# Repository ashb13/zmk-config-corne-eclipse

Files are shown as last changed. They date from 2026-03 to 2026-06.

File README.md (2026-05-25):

README | [Keymap](KEYMAP.md) | [MX Parts](PARTS_MX.md) | [Building](BUILDING.md) | [Tricks](TRICKS.md)

# Corne Eclipse

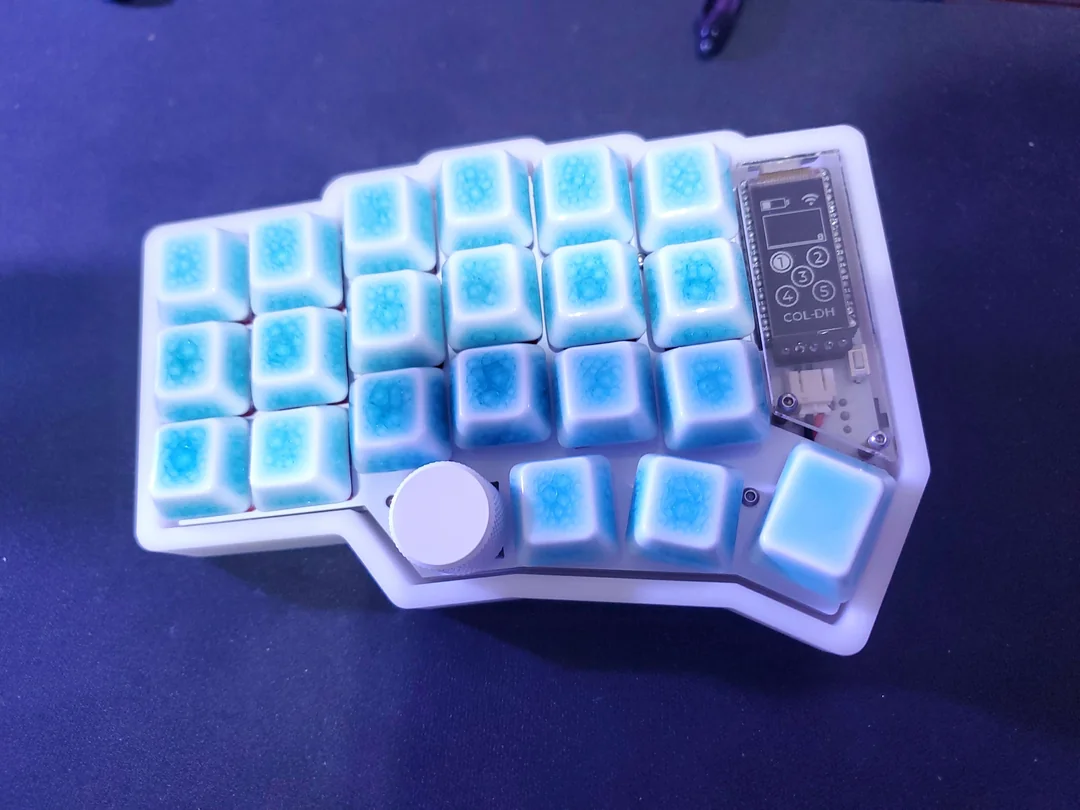
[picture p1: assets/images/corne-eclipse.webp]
Corne Eclipse With Ceramic Keys


---

Corne Eclipse Front And Back

The Corne Eclipse is a highly customized wireless Corne MX.

*This was a project I initially finished in 2021. Finally updated and open sourced!*

## Custom Circuit Board Design

- JST port with line passthrough for undercarriage battery storage
- Native support for dual nice!view displays
- Native support for dual Alps EC11/EC12 encoders
- Native support for heftier side mounted power switches
- Native support for tenting puck

## Custom Shield Casing Design

Based on Void's case.

- Undercarriage battery storage
- Optimized material usage for bottom
- Native support for tenting puck

## Peripheral-side Trackpad Support

- TPS43 (and related Azoteq IQS5xx modules) via [AYM1607/zmk-driver-azoteq-iqs5xx](https://github.com/AYM1607/zmk-driver-azoteq-iqs5xx)
- Cirque Touchpad via [petejohanson/cirque-input-module](https://github.com/petejohanson/cirque-input-module)

## ZMK Modifications

### External Display Upgrades

- Lithium curve LUT applied for a 403450 to get more accurate numeric charge data (PR reference: [ZMK PR 2066](https://github.com/zmkfirmware/zmk/pull/2066))
- Track battery status of both halves on a single nice!view
- Capslock indicator

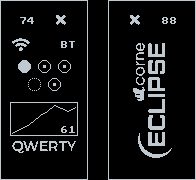
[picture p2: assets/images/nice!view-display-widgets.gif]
nice!view Display Widgets


### RGB Battery Optimizations

Powered by [zmk-ext-power-smart-idle](https://github.com/Frosthaven/zmk-ext-power-smart-idle).

- 20% brightness when not plugged in
- RGB auto-off on low battery when not plugged in
- Lights stay on when plugged in
- Eclipse v3 reversible variant uses a MOSFET that prevents drain when LEDs are off (coming soon)

## Default Typing Layouts

Available in [releases](https://github.com/ashb13/zmk-config-corne-eclipse/releases).

- QWERTY
- Colemak Mod DH (personal choice!)
- Colemak
- Workman
- DVORAK

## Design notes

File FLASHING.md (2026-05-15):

# Flashing Firmware

This guide covers how to flash firmware to the Corne Eclipse keyboard. Each half of the keyboard must be flashed separately.

## Entering Bootloader Mode

There are two ways to put a keyboard half into bootloader mode:

### Option 1: From the System Layer

1. Activate the **SYSTEM** layer (hold both lower and raise keys simultaneously)
2. Press the **Bootloader** key on the side you want to flash
   - The left **Bootloader** key puts the **left half** into bootloader mode
   - The right **Bootloader** key puts the **right half** into bootloader mode

### Option 2: Using the Physical Reset Switch

If the keyboard is unresponsive or you can't access the system layer:

1. Locate the **reset switch** on top of the board, above the power switch
2. Press the reset switch **twice in quick succession** (double-tap)
3. The keyboard half will enter bootloader mode

## Choosing the Right Firmware

Each release ships **one zip per typing layout**. Inside that zip you'll find a default and trackpad variant for each half plus a settings-reset image. You pick which `.uf2` to flash to each half based on what you've installed on that side.

`<layout>` is one of `qwerty`, `colemak_dh`, `colemak`, `workman`, `dvorak`.

```
corne_eclipse_<layout>.zip
├── left_corne_eclipse_<layout>.zmk.uf2            ← default left half
├── left_trackpad_corne_eclipse_<layout>.zmk.uf2   ← left half with trackpad instead of display
├── right_corne_eclipse_<layout>.zmk.uf2           ← default right half
├── right_trackpad_corne_eclipse_<layout>.zmk.uf2  ← right half with trackpad instead of display
└── settings_reset-nice_nano_v2-zmk.uf2            ← clean-slate / factory reset
```

**Which file do I flash to each half?**

The PCB is reversible, so you can install a trackpad on either half (or both halves, if you want two trackpads). Pick the variant per half independently:

| File | Flash to | Use when |
|---|---|---|
| `left_corne_eclipse_<layout>.zmk.uf2` | Left half | Default. Use this unless you've installed a trackpad on the left half. nice!view display is supported but optional; this firmware works with or without it. |
| `left_trackpad_corne_eclipse_<layout>.zmk.uf2` | Left half | Only if you've installed a trackpad (Azoteq IQS5xx **or** Cirque Pinnacle) on the left half. The display is disabled since the trackpad uses the display's pins. |
| `right_corne_eclipse_<layout>.zmk.uf2` | Right half | Default. Use this unless you've installed a trackpad on the right half. nice!view display is supported but optional; this firmware works with or without it. |
| `right_trackpad_corne_eclipse_<layout>.zmk.uf2` | Right half | Only if you've installed a trackpad (Azoteq IQS5xx **or** Cirque Pinnacle) on the right half. The display is disabled since the trackpad uses the display's pins. The encoder/switch still works. |

The trackpad variants bundle both Azoteq and Cirque drivers, so a single firmware works for either trackpad type. See [WIRING_TRACKPAD.md](WIRING_TRACKPAD.md) for trackpad wiring.

## Flashing the Firmware

Once a keyboard half is in bootloader mode, it will appear as a USB drive on your computer (named **NICENANO**).

1. Download `corne_eclipse_<layout>.zip` from the [releases](https://github.com/Frosthaven/zmk-config-corne-eclipse/releases) page for your desired typing layout
2. Extract the zip
3. **(Recommended)** Flash `settings_reset-nice_nano_v2-zmk.uf2` to **both halves** first to wipe any saved RGB / BLE / layer state from previous firmware. Otherwise stale NVS can override the new firmware's defaults (e.g. show wrong RGB color, stuck brightness).
4. Put the **left half** into bootloader mode
5. Drag and drop the left-half `.uf2` of your choice (default or `left_trackpad_`) onto the **NICENANO** drive
6. The drive will disconnect automatically when flashing is complete
7. Put the **right half** into bootloader mode
8. Drag and drop the right-half `.uf2` of your choice (default or `right_trackpad_`) onto the **NICENANO** drive
9. The drive will disconnect automatically when flashing is complete

Both halves should now be running the new firmware.

> ⚠️ **The keyboard half must be physically connected to your computer via USB for the `NICENANO` drive to appear.** The reset switch / bootloader key only puts the half into bootloader mode; it does not expose the drive over Bluetooth. If no drive appears after a few seconds: confirm the USB cable is a data cable (not charge-only), try a different USB port, and verify the half is actually in bootloader mode.

## RGB While Building (assembly testing)

A `_rgb_while_building_corne_eclipse.zip` bundle is also produced. Its firmware enables RGB underglow at boot so you can verify the LED chain without needing to find `RGB_TOG` in your keymap yet. Smart-idle still applies, so the LEDs follow the usual fade-off rules (30 seconds of idle on battery, 2 hours of idle on USB). QWERTY layout. Not intended for daily use.

The leading underscore in the zip name keeps this bundle at the top of the release page, separated from the daily-use layouts.

Inside the zip:

- `left_corne_eclipse_rgb_while_building.zmk.uf2` for the left half
- `right_corne_eclipse_rgb_while_building.zmk.uf2` for the right half
- `settings_reset-nice_nano_v2-zmk.uf2`

Recommended assembly sequence: **settings_reset → rgb_while_building → confirm LEDs → settings_reset → daily layout build**. The settings reset before each flash ensures the firmware's defaults take effect instead of stale NVS state.

## Resetting to Factory Settings

The `settings_reset-nice_nano_v2-zmk.uf2` is bundled inside every release zip. Flash it whenever you want to wipe stored settings (RGB state, BLE pairings, layer state, etc.) or as a clean-slate step before flashing new firmware.

1. Extract the zip you downloaded
2. Flash `settings_reset-nice_nano_v2-zmk.uf2` to **both halves** using the steps above
3. After resetting both halves, flash your desired layout firmware to both halves again

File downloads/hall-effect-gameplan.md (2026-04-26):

# Hall Effect Corne Eclipse — Implementation Gameplan

## Overview

This document details the full plan to create a hall effect (HE) variant of the Corne Eclipse split keyboard, covering PCB design, component selection, firmware integration with ZMK, and known risks.

---

## 1. Architecture Comparison

| Feature | Current Corne Eclipse | Hall Effect Variant |
|---|---|---|
| Switch type | Mechanical (Choc v1/v2, Cherry MX) | Hall effect magnetic (e.g. Gateron KS-20) |
| Sensing method | Digital matrix scan (row × col) | Analog voltage per switch via hall sensor |
| Switch pins | 2 signal pins (matrix intersection) | 3 pins (VCC, GND, analog signal) |
| Scan hardware | Direct GPIO matrix | Analog multiplexers → ADC |
| MCU | Nice!Nano (nRF52840) | Same — nRF52840 has 8 ADC channels |
| Firmware | ZMK (standard kscan driver) | ZMK + community HE module |
| Features unlocked | N/A | Adjustable actuation, rapid trigger, SOCD |

---

## 2. Component Selection

### 2.1 Hall Effect Switches

**Primary candidate: Gateron KS-20 series**
- MX-compatible housing (fits standard MX plate cutouts — 14×14mm)
- 3-pin: VCC, GND, analog signal output
- Adjustable actuation range: 0.4mm–3.6mm
- Total travel: 4.1±0.2mm
- Built-in hall effect sensor (no external sensor IC needed)
- Available in multiple spring weights (Orange 38gf, White 30gf)

**Alternative: 3D-printed Void Switches** (community, uses discrete hall sensor IC like A1304)

**Note:** Hall effect switches are NOT pin-compatible with Cherry MX mechanical switches. The center pin and signal pin positions differ. A new footprint is required.

### 2.2 Analog Multiplexers

**CD4067B (16:1 analog mux)** — industry standard
- 16 analog channels switched to 1 common output
- 4 digital select lines (S0–S3) + 1 enable
- Package: SOIC-24 or TSSOP-24
- Supply: 3.0–18V (works at 3.3V from Nice!Nano)
- On-resistance: ~125Ω at 3.3V (acceptable for analog sensing)
- Propagation delay: ~250ns

**Per-half requirements (21 switches + 1 encoder = 22 analog channels):**
- 2× CD4067B per half (16 + 6 channels used, 10 spare)
- Shared select lines: 4 GPIO pins for S0–S3
- 2 ADC pins (one per mux output)
- 2 GPIO for enable pins (optional, for power saving)

### 2.3 MCU: Nice!Nano v2 (nRF52840)

**Available ADC pins (AIN0–AIN7 on nRF52840):**

| ADC Channel | Pin | Nice!Nano Usage | Available? |
|---|---|---|---|
| AIN0 | P0.02 | GPIO | Yes |
| AIN1 | P0.03 | GPIO | Yes |
| AIN2 | P0.04 | Battery voltage | **No — reserved** |
| AIN3 | P0.05 | GPIO | Yes |
| AIN4 | P0.28 | GPIO | Yes |
| AIN5 | P0.29 | GPIO | Yes |
| AIN6 | P0.30 | GPIO | Yes |
| AIN7 | P0.31 | GPIO | Yes |

**Available: 7 ADC channels** (AIN2 reserved for battery). Only 2 needed for the mux outputs. Remaining 5 are available for other analog functions if needed.

**GPIO needed per half:**
- 4× mux select lines (S0–S3, shared between both muxes)
- 2× mux enable (optional)
- 2× ADC input (one per mux)
- Total: 6–8 GPIO/ADC pins for the switch matrix

This leaves enough remaining pins for: RGB LED data, I2C (OLED/nice!view), encoder, reset, battery.

### 2.4 Passive Components

- 2× 0.1µF bypass capacitors per CD4067B (VDD-VSS decoupling)
- 1× 10µF bulk capacitor per half (power rail stabilization)
- Optional: RC low-pass filter per mux output (e.g. 100Ω + 10nF) to reduce ADC noise

---

## 3. PCB Design

### 3.1 What Carries Over From Current Design

- Board outline / Edge.Cuts (identical form factor)
- Mounting holes and tenting puck positions
- Nice!Nano MCU footprint and placement
- Nice!View connector position
- JST battery connector
- TRRS/serial connection (for wired split, if used)
- Case, plate, and cover geometry
- GLOW underglow LED positions and wiring (WS2812B chain is independent of switch sensing)
- RGBMOS power switching circuit

### 3.2 What Must Change

**Switch footprint — NEW required:**
- Hall effect switches (Gateron KS-20) have 3 pins in different positions than MX
- Need: VCC, GND, and signal traces per switch
- Center post hole likely similar to MX (4mm) but verify against KS-20 datasheet
- Plate cutout: 14×14mm (same as MX, so existing MX plates may work)
- No hotswap socket — KS-20 switches are PCB-mount (solder-in) unless a HE-specific hotswap socket exists

**No row/col matrix — replaced with:**
- VCC bus: all switches share a common 3.3V power rail
- GND bus: all switches share common ground
- Individual signal traces: each switch's analog output routes to one mux input
- Mux outputs route to MCU ADC pins

**New components on PCB:**
- 2× CD4067B multiplexer ICs (SOIC-24 or TSSOP-24)
- Bypass capacitors
- Optional analog filtering

**Removed from PCB:**
- Diodes (no matrix → no diodes needed, saves 42 components per board)
- Row/column traces

### 3.3 Wiring Diagram (Per Half)

```
                        ┌─────────────┐
  Switch 1  signal ───▶ │ CH0         │
  Switch 2  signal ───▶ │ CH1         │
  Switch 3  signal ───▶ │ CH2         │
  ...                   │   CD4067B   │──▶ COM ──▶ MCU ADC AIN0
  Switch 16 signal ───▶ │ CH15    #1  │
                        │             │
                        │ S0 S1 S2 S3 │◀── MCU GPIO (shared)
                        │ EN          │◀── MCU GPIO (optional)
                        └─────────────┘

                        ┌─────────────┐
  Switch 17 signal ───▶ │ CH0         │
  Switch 18 signal ───▶ │ CH1         │
  ...                   │   CD4067B   │──▶ COM ──▶ MCU ADC AIN1
  Switch 22 signal ───▶ │ CH5     #2  │
                        │             │
                        │ S0 S1 S2 S3 │◀── MCU GPIO (shared with #1)
                        │ EN          │◀── MCU GPIO (optional)
                        └─────────────┘

  All switches VCC ──── 3.3V rail
  All switches GND ──── GND rail
```

### 3.4 PCB Layout Guidelines

1. **Keep analog traces short** — route switch signals to the nearest mux with minimal trace length to reduce noise pickup
2. **Separate analog and digital** — don't route mux select lines parallel to analog signal traces
3. **Ground plane** — use a solid ground pour under the mux ICs and analog traces
4. **Bypass caps** — place 0.1µF caps as close as possible to each CD4067B VDD/VSS pins
5. **Mux placement** — place one mux near the main key cluster, one near the thumb cluster or split between regions to minimize trace lengths
6. **Star ground** — connect all switch GND pins and mux GND to the same ground pour, avoid daisy-chaining
7. **ADC trace routing** — keep mux COM output → MCU ADC traces short and away from digital noise (RGB data line, I2C clock, etc.)
8. **Optional low-pass filter** — place RC filter pads between mux COM output and ADC input for noise reduction

### 3.5 Per-Key LED Consideration

SHINE per-key LEDs (LED_choc_6028R reverse mount) can remain, but:
- The LED light-pipe hole position must align with the KS-20's LED window (verify against KS-20 datasheet — may differ from MX)
- If KS-20 doesn't have an LED window, per-key backlighting through the switch won't work and LEDs should be repositioned or removed
- Underglow (GLOW WS2812B) is unaffected

---

## 4. Firmware: ZMK Integration

### 4.1 Community Module

**Repository:** [cr3eperall/zmk-feature-hall-effect](https://github.com/cr3eperall/zmk-feature-hall-effect)

**Features provided:**
- Adjustable actuation point (runtime configurable)
- Rapid trigger (re-actuation on direction change)
- SOCD (simultaneous opposing cardinal direction handling)
- Mouse input emulation
- Gamepad input emulation
- Split keyboard support (`he,input-split` binding)

**Drivers available:**
- `he,kscan-direct-pulsed` — for direct ADC wiring (not practical for 42 switches)
- `he,kscan-multiplexer` — for CD4067B mux wiring (this is what we need)

### 4.2 Integration Steps

1. **Add module to ZMK config:**
   ```yaml
   # In west.yml manifest
   projects:
     - name: zmk-feature-hall-effect
       url: https://github.com/cr3eperall/zmk-feature-hall-effect
       revision: main
   ```

2. **Create devicetree overlay** for the Corne Eclipse HE variant:
   - Define 2× CD4067B mux instances with select GPIO pins and ADC channel
   - Map each switch to a mux channel
   - Configure actuation thresholds, rapid trigger parameters
   - Set up `he,input-split` for the peripheral half

3. **Calibration routine:**
   - Each hall sensor has slightly different voltage range
   - Need to implement or use the module's calibration to map raw ADC values → distance
   - Store calibration data in flash/settings

4. **Battery monitoring:**
   - The module includes a custom battery driver for nRF52840
   - AIN2 (P0.04) remains dedicated to battery voltage sensing (unchanged)

### 4.3 Known Firmware Limitations

- **nRF52840 ADC anomaly (errata 212):** certain chip revisions (CKAA-Dx0 or QIAA-Dx0) have a bug where switching between single-channel and multi-channel ADC modes breaks the ADC. The module works around this by using single-mode continuously. Verify your Nice!Nano's chip revision.
- **Scan rate:** analog sensing is slower than digital matrix scan. With 2 muxes × 16 channels × ADC conversion time (~15µs per sample at 10-bit), expect ~0.5ms per full scan — still well under 1ms, adequate for 1000Hz+ polling.
- **No official ZMK merge yet:** the community module is not part of mainline ZMK. You depend on the module author for updates. However, PR #2980 on the ZMK repo suggests official support is being worked on.

---

## 5. Implementation Phases

### Phase 1: Validate Hardware (1–2 weeks)
- [ ] Obtain Gateron KS-20 switches and measure exact pin positions, center post diameter, and overall dimensions
- [ ] Create KiCad footprint for KS-20 (or find community footprint)
- [ ] Prototype one switch + CD4067B + Nice!Nano on a breadboard/perfboard
- [ ] Verify ADC readings through the mux with the cr3eperall ZMK module
- [ ] Test calibration and actuation point adjustment
- [ ] Verify Nice!Nano chip revision for ADC errata 212

### Phase 2: PCB Design (2–3 weeks)
- [ ] Copy the Corne Eclipse MX board as starting point (outline, mounting holes, MCU, connectors)
- [ ] Remove all SW/ENC footprints, diodes, and matrix traces
- [ ] Create and place KS-20 switch footprints at same grid positions
- [ ] Place 2× CD4067B mux ICs per half
- [ ] Route VCC/GND buses to all switches
- [ ] Route individual analog signal traces from switches to mux inputs
- [ ] Route mux select lines (4× GPIO) and COM outputs (2× ADC)
- [ ] Add bypass caps and optional RC filters
- [ ] Run DRC, verify clearances
- [ ] Update plate files if KS-20 cutout differs from MX

### Phase 3: Firmware (1–2 weeks, parallel with Phase 2)
- [ ] Fork ZMK config, add cr3eperall/zmk-feature-hall-effect module
- [ ] Write devicetree overlay for Corne Eclipse HE with mux driver
- [ ] Implement per-switch channel mapping
- [ ] Configure split keyboard communication with `he,input-split`
- [ ] Test rapid trigger and SOCD features
- [ ] Implement and test calibration storage

### Phase 4: Fabrication & Assembly (2–3 weeks)
- [ ] Order PCBs (JLCPCB, same process as current boards)
- [ ] Order components: KS-20 switches, CD4067B, passives
- [ ] Solder and assemble
- [ ] Flash firmware, run calibration
- [ ] Verify all 42 switches respond with correct analog range
- [ ] Test split communication, battery life, RGB

### Phase 5: Refinement
- [ ] Tune actuation points and rapid trigger sensitivity
- [ ] Profile battery life impact (analog sensing draws more power than digital matrix)
- [ ] Consider power optimization: disable mux enable pins when idle, reduce scan rate during idle
- [ ] Evaluate whether per-key LEDs align with KS-20 LED window

---

## 6. Bill of Materials (Per Half)

| Component | Quantity | Package | Notes |
|---|---|---|---|
| Gateron KS-20 switch | 21 (+1 encoder?) | Through-hole | Verify encoder compatibility |
| CD4067B mux | 2 | SOIC-24 or TSSOP-24 | 16-ch analog mux |
| 0.1µF ceramic cap | 4 | 0402 or 0603 | Mux bypass (2 per mux: VDD-VSS, VEE-VSS) |
| 10µF ceramic cap | 1 | 0603 or 0805 | Bulk power rail decoupling |
| 100Ω resistor (optional) | 2 | 0402 or 0603 | RC filter per mux output |
| 10nF ceramic cap (optional) | 2 | 0402 or 0603 | RC filter per mux output |
| Nice!Nano v2 | 1 | Module | nRF52840-based |
| Nice!View | 1 | Module | OLED display |
| WS2812B (GLOW) | 6 | PLCC4 5×5mm | Underglow LEDs (unchanged) |
| LED_6028R (SHINE) | 21 | 6028 reverse mount | Per-key LED (if KS-20 has LED window) |
| AO3401A MOSFET | 1 | SOT-23-3 | RGB power switch (unchanged) |
| Resistors (RGB) | 1 | 0402/0603 | Gate pullup for MOSFET (unchanged) |
| JST connector | 1 | PH 2-pin | Battery (unchanged) |
| Tenting puck mount | 1 | Custom | 3× M2 holes (unchanged) |

---

## 7. Open Questions & Risks

1. **KS-20 exact footprint** — no public KiCad footprint exists. Need to measure switches or find community footprint. Pin positions, center post size, and alignment pin locations are unknown until hands-on measurement.

2. **Hotswap for HE switches?** — standard Kailh hotswap sockets won't work (different pin layout). Mill-Max sockets on individual pins might work but adds height and cost. Likely solder-only initially.

3. **Encoder compatibility** — the rotary encoder (EC11/EC12) is a mechanical device, not hall effect. It can remain as-is with its own GPIO pins. However, if a switch shares the encoder position (ENC_SW combo footprint), that switch portion needs to be hall effect while the encoder remains digital. This requires careful pin routing — the encoder's digital output goes to GPIO, the switch's analog output goes to mux.

4. **Battery life** — analog sensing draws more current than passive digital matrix scan. The CD4067B draws ~100µA quiescent, and each ADC conversion consumes MCU power. Estimate 10–20% reduction in battery life vs current design. Can be mitigated by reducing scan rate during idle and disabling mux enable pins during sleep.

5. **Nice!Nano chip errata** — verify your specific Nice!Nano's nRF52840 chip revision isn't affected by ADC errata 212. If affected, you're limited to single-channel ADC mode (still workable with the mux approach since you read one channel at a time).

6. **Module stability** — the cr3eperall ZMK module is community-maintained, not official. If the author abandons it and ZMK's mainline PR (#2980) isn't merged, you'd need to maintain it yourself.

7. **Plate compatibility** — Gateron KS-20 uses an MX-compatible housing, so the 14×14mm plate cutout SHOULD work. Verify that the KS-20's bottom protrusions clear your current plate thickness (1.5mm for MX plates).

---

## 8. Reference Links

- [cr3eperall/zmk-feature-hall-effect](https://github.com/cr3eperall/zmk-feature-hall-effect) — ZMK community module for HE support
- [ZMK Issue #2096 — Hall Effect Support Discussion](https://github.com/zmkfirmware/zmk/issues/2096) — official issue tracker
- [ZMK PR #2980 — Hall Keyscan Driver](https://github.com/zmkfirmware/zmk/pull/2980) — WIP official driver
- [Macrolev — Open Source HE Keyboard](https://github.com/heiso/macrolev) — reference split HE keyboard design
- [Void Switch 65% — Reference HE PCB](https://github.com/riskable/void_switch_65_pct) — KiCad reference project
- [Gateron KS-20 Product Page](https://www.gateron.com/products/gateron-ks-20-magnetic-orange-hall-sensor-switch-set) — switch specs
- [CD4067B Datasheet & Design Guide](https://components101.com/article/cd4067-16-channel-analog-multiplexer-demultiplexer) — mux reference
- [nRF52840 ADC Pin Mappings](https://tomasmcguinness.com/2025/01/12/nrf52840-adc-pin-mappings/) — ADC channel reference
- [Nice!Nano Pinout](https://nicekeyboards.com/docs/nice-nano/pinout-schematic/) — MCU pin availability
- [Hall Effect Keyboard Sensing Explained — Deskthority](https://deskthority.net/viewtopic.php?t=18163) — theory and wiring

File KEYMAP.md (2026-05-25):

[README](README.md) | Keymap | [MX Parts](PARTS_MX.md) | [Building](BUILDING.md) | [Tricks](TRICKS.md)

## Keymap

Inspired by Cyberpunk's story of Johnny Silverhand, the Corne Eclipse comes with
the SAMURAI layout. I've used this layout since 2020 to slay everything from
video game corporations in a dystopian city to software development on the job.

The strategy I used when developing this layout is much like the strategy used
by vim/neovim: keep keys grouped by concept as much as possible. You can see
this in part by how movement is managed:

- The same key locations for movement in video games are reused for the arrow
  keys and again for mouse direction.
- The numpad is laid out like a full keyboard's numpad.

With this strategy, it makes leveraging all of the keys a lot more intuitive
than it seems at first glance.

## ZMK Studio

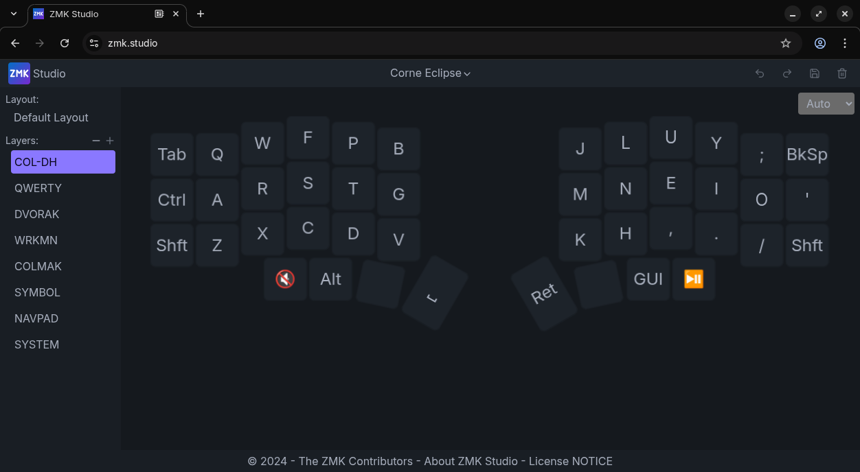
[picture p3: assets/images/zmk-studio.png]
ZMK Studio


This firmware supports [ZMK Studio](https://zmk.studio/) for changing *most* key
bindings without reflashing. You can read more about its features and
limitations on the [official documentation page](https://zmk.dev/docs/features/studio).

### Usage

1. Connect the left half via USB
2. Make sure the keyboard is in USB mode (use the `BT or USB` key on the `SYSTEM` layer to toggle)
3. Open ZMK Studio and connect
4. When prompted to unlock, press the `ZMK AUTH` key on the `SYSTEM` layer

On Linux, you may need serial port access (log out and back in after):

```bash
sudo usermod -aG uucp $USER
```

### Reset To Firmware Default Keymap

To revert to the firmware's default keymap, use the "Restore Stock Settings"
option in ZMK Studio.

## Keyboard Layers

### Typing Layers

Beyond your default typing layout, you can activate layouts 2, 3, 4, and 5 on
the `SYSTEM` layer. By default all layouts are filled with alternative keymaps:

- QWERTY
- Colemak-DH
- Colemak
- Dvorak
- Workman

The default typing layout is decided by which firmware package you install from
the [releases](https://github.com/Frosthaven/zmk-config-corne-eclipse/releases)
page. You can always return to your default layout by pressing the `LAYOUT 1`
key on the `SYSTEM LAYER`.

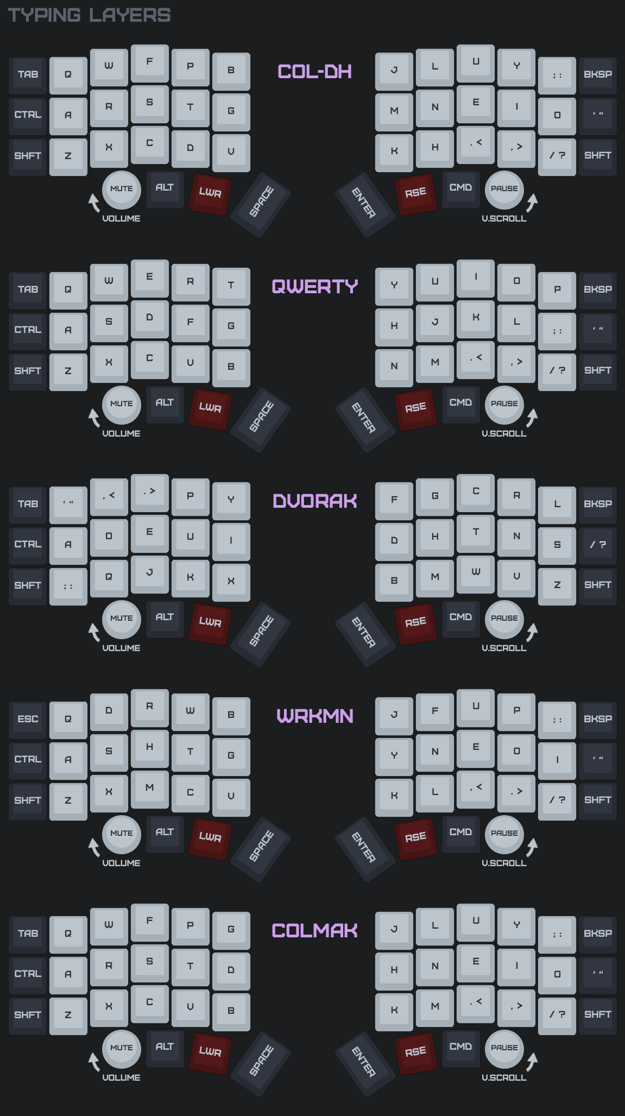
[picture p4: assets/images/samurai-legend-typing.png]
Typing Layer


### Utility Layers

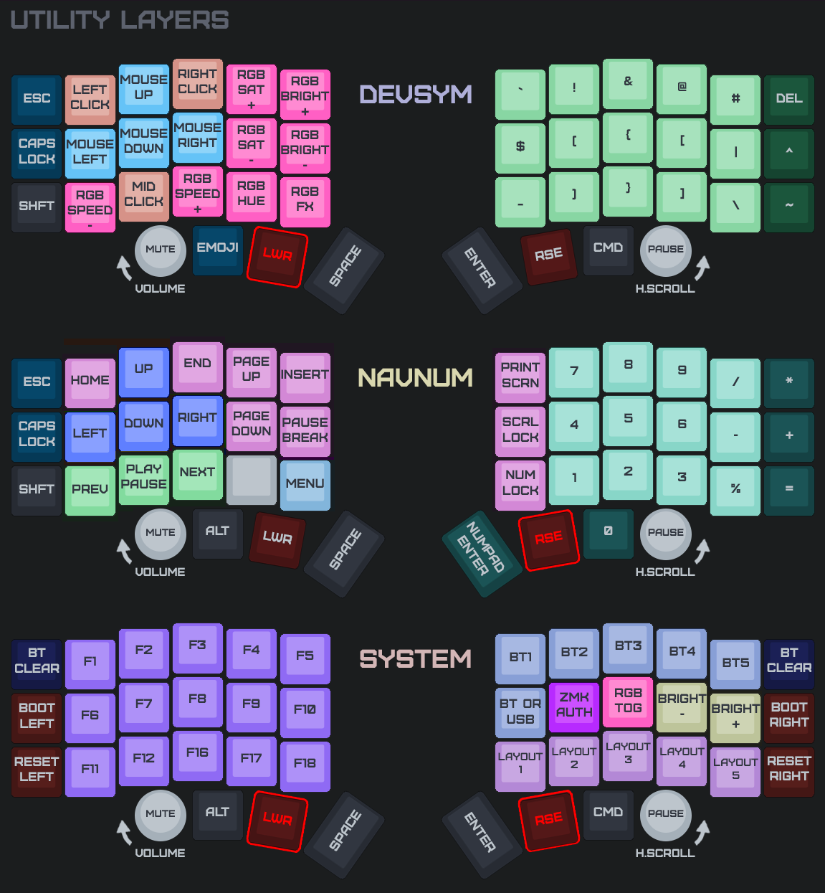
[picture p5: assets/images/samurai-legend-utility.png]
Utility Layer


## MacOS Specific Notes

<details>
<summary>Omni-shortcuts for Navigation and Text Editing</summary>

Ideally, you'd want to get used to the different keybinds on different operating
systems to save yourself a headache later. However, you can use
Karabiner-Elements to bridge the divide between Linux/Windows and Mac for most
things.

Install [Karabiner-Elements](https://karabiner-elements.pqrs.org/) via Homebrew:

```bash
brew install --cask karabiner-elements
```

Then paste the following URL into your browser address bar to import the
Omni-shortcuts:

```
karabiner://karabiner/assets/complex_modifications/import?url=https://raw.githubusercontent.com/ashb13/zmk-config-corne-eclipse/main/assets/references/karabiner-windows-shortcuts.json
```

*Note: Make sure that Corne Eclipse has both `Modify events` and `Ignore vendor
events` toggled on in Karabiner-Elements' Devices tab.*

Three rule groups — **Text Navigation**, **Text Editing**, and **App Shortcuts** — remap common shortcuts so Linux/Windows muscle memory carries over on macOS. All rules exclude terminal apps to preserve signals like `Ctrl+C`. Note: `Ctrl+Left/Right` overrides macOS Space switching (previous/next desktop).

| Key | Action |
|-----|---|
| `Home` | Beginning of line |
| `End` | End of line |
| `Shift+Home` / `Shift+End` | Select to line start/end |
| `Ctrl+Home` / `Ctrl+End` | Beginning/end of document |
| `Shift+Ctrl+Home` / `Shift+Ctrl+End` | Select to document start/end |
| `Ctrl+Left` / `Ctrl+Right` | Jump word left / right |
| `Ctrl+Shift+Left` / `Ctrl+Shift+Right` | Select word left / right |
| `Ctrl+Backspace` | Delete word backward |
| `Ctrl+Delete` | Delete word forward |
| `Ctrl+C` / `X` / `V` | Copy / Cut / Paste |
| `Ctrl+Z` / `Ctrl+Y` / `Ctrl+Shift+Z` | Undo / Redo |
| `Ctrl+A` | Select All |
| `Ctrl+S` / `Ctrl+Shift+S` | Save / Save As |
| `Ctrl+F` | Find |
| `Ctrl+R` | Reload |
| `Ctrl+W` | Close tab |
| `Ctrl+T` | New tab |
| `Ctrl+N` / `Ctrl+Shift+N` | New window / Private window |
| `Ctrl+O` | Open file |
| `Ctrl+L` | Focus address bar |
| `Ctrl+P` / `Ctrl+Shift+P` | Print / Command palette |
| `Ctrl+K` | In-app search |
| `Ctrl+D` | Bookmark / select next occurrence |
| `Ctrl+B` | Bold / toggle sidebar |
| `Ctrl+I` | Italic |

</details>

<details>
<summary>Tap Command alone → launch Raycast</summary>

A modifier-tap rule turns the Command key into a [Raycast](https://www.raycast.com/) launcher when tapped on its own: hold Command and it behaves normally for shortcuts (e.g. `Cmd+S`), tap and release it alone and it fires `Control+Space` (Raycast's default global hotkey). Released using Karabiner's `to_if_alone` with `lazy: true`, so holding Command never registers as a key event until another key joins it — there's no menu flash or stray modifier press.

Bundled into the same `karabiner-windows-shortcuts.json` import URL as the omni-shortcuts above. The rule shows up in Karabiner as a separate enable/disable toggle, so you can leave it off if you'd rather not lose tap-Command.

| Key | Action |
|-----|---|
| Tap `Cmd` (no other key) | Launch / toggle Raycast |
| Hold `Cmd` + any key | Normal Command behavior |

*Note: requires Raycast's global hotkey to be set to `Control+Space` (the default). If you've changed it, update the `to_if_alone` binding in the rule to match.*

</details>

## Linux Specific Notes

<details>
<summary>Using the Emoji key</summary>

The emoji key on the `DEVSYM` layer is a macro that presses the keys necessary
to launch the emoji picker on Windows and on MacOS. For Linux, you may need to
assign this key to your emoji picker of choice if one is not already assigned
(I'm a big fan of `smile` under Wayland). When you press the emoji key, it will
likely be detected as `Super + period`.

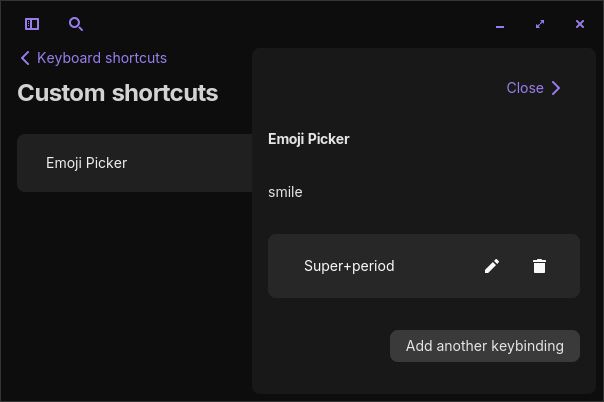
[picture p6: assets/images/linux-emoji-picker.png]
Linux Emoji Picker


</details>

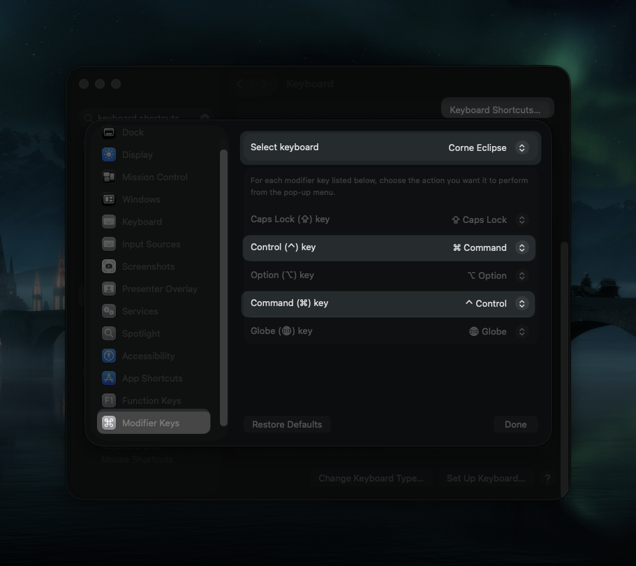
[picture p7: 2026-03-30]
assets/images/mac-rebind-modifiers.png

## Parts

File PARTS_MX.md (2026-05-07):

[README](README.md) | [Keymap](KEYMAP.md) | MX Parts | [Building](BUILDING.md) | [Tricks](TRICKS.md)

# MX Parts

## Electronics

| Required | Quantity | Part | Notes |
|---|---|---|---|
| ✅ | 2 | [nice!nano v2 Microcontroller](https://nicekeyboards.com/nice-nano/) | Bluetooth-enabled. Solder at 270-300C to avoid damaging the nRF52840 chip. |
| ✅ | 2 | [JST Connector (S2B-PH-SM4-TB)](https://www.digikey.com/en/products/detail/jst-sales-america-inc/S2B-PH-SM4-TB/926655) | For battery connection with line passthrough. |
| ✅ | 2 | [SPDT Right-Angle Slide Switch](https://www.digikey.com/en/products/detail/eao/09-10290-01/8733108) | Power switch. |
| ✅ | 2 | [750mAh Battery (403450)](https://www.amazon.com/Liter-energybattery-Battery-Rechargeable-Connector/dp/B09FSY7N9G) | 3.7V LiPo, 4 x 34 x 50mm. JST PH 2.0 terminated. Important: The hot (red) line of the battery should go on the right side when looking down at either corne pcb from above. |
| ✅ | 100+ | [SMD Diodes](https://boardsource.xyz/products/diode-smd) | 1N4148W or equivalent. |
| ✅ | 42+ | [MX Hotswap Sockets](https://cannonkeys.com/products/kailh-mx-hotswap-sockets) | For plugging your switches into. |
| ✅ | 2 | [Mill Max Low Profile Sockets & Pins](https://splitkb.com/products/mill-max-low-profile-sockets?variant=31945995845709) | For socketing the nice!nano. Make sure you get the Mil Max pins with it! |
| ✅ | 2 | [Reset Switches](https://splitkb.com/products/reset-buttons) | Tactile SMD reset switches. |
| ❌ | 1-2 | [nice!view Display](https://nicekeyboards.com/nice-view/) | The left is the most important, as it shows active bluetooth state and profile. Be sure to get pins/sockets that accomodate your socketing height of the nice!nano. |
| ❌ | 1-2 | [Alps EC11 Rotary Encoder](https://www.mouser.com/ProductDetail/Alps-Alpine/EC11N1524402?qs=W%2FMpXkg%252BdQ5mmk2EdvtXAA%3D%3D) | Alps Alpine EC11N1524402 or EC11 compatible encoder. |
| ❌ | 1 | [Azoteq TPS43 Touchpad Module](https://holykeebs.com/products/touchpad-module) | Replaces the right encoder. Requires 5 wires (SDA, SCL, RDY, VCC, GND) to the nice!nano. See [wiring guide](WIRING_TRACKPAD.md). |

## Switches & Keycaps

| Required | Quantity | Part | Notes |
|---|---|---|---|
| ✅ | 42+ | MX Switches | MX-compatible switch set. |
| ✅ | 42+ | MX Keycaps | MX-compatible keycap set. |
| ❌ | 1-2 | [Encoder Rotary Knobs](https://www.gloriousgaming.com/products/gmmk-pro-keyboard-rotary-knob) | Any EC11-compatible knobs if you installed an encoder. |

## Plates & Case

| Required | Quantity | Part | Notes |
|---|---|---|---|
| ❌ | 2 | [OLED Cover Kit](https://keebd.com/en-us/products/corne-acrylic-oled-cover-kit) | Protective acrylic covers. If you find these without the standoffs and screws, you'll need to get those yourself. |
| ❌ | 2 | [SplitKB Tenting Pucks](https://splitkb.com/products/tenting-puck?_pos=1&_sid=b9942abea&_ss=r) | Mounted to the PCB via 4 included screws. May have options that include the Manfrotto MP3-BK. |
| ❌ | 2 | [Small Desk Tripod](https://www.manfrotto.com/global-en/pocket-support-large-black-mp3-bk/) | Manfrotto MP3-BK Pocket Tripod or similar. Only if you didn't get it bundled above. |

## Hardware

I haven't yet verified the exact screws, so this list may not be exact. YMMV.

| Required | Quantity | Part | Notes |
|---|---|---|---|
| ✅ | 10 | [M2x8mm Countersunk Screws](https://www.aliexpress.us/item/2251832781782755.html) | Standoff bottom case screws. |
| ✅ | 36 | [M2x5mm Button Head Screws](https://www.aliexpress.us/item/2251832780910689.html) | Standoff top plate screws. |
| ✅ | 10 | [M2x4mm Female-Female Standoffs](https://www.amazon.com/dp/B0FLGTQZNN) |  |

## Fabrication

While the sections above cover items you can buy, this section documents
what needs to be created.

The circuit board, plates, and shields need to be fabricated by a PCB and 3D
printing company like [Elecrow](https://www.elecrow.com/),
[JLCPCB](https://jlcpcb.com/), [PCBWay](https://www.pcbway.com/), or
[OSHPark](https://oshpark.com/). I've had good work from Elecrow in the past.

### Circuit Board

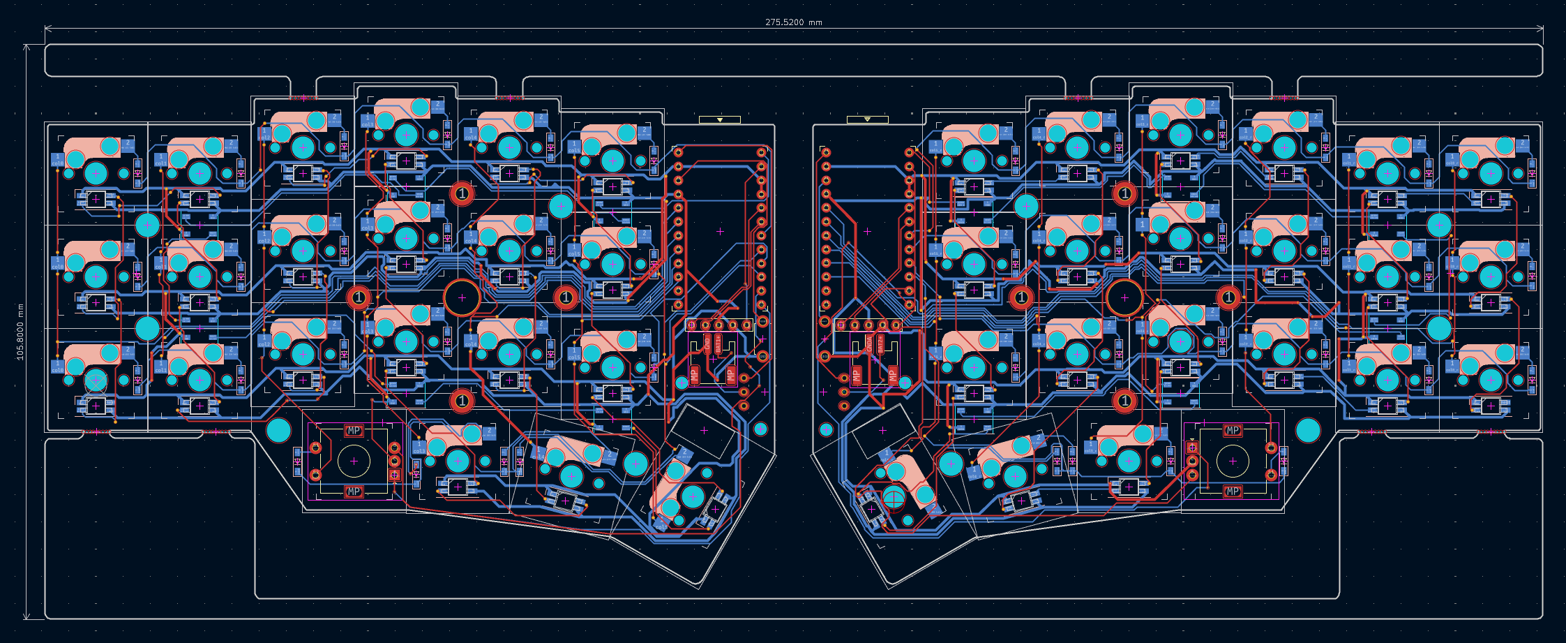
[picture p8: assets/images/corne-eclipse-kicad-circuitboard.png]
Circuit Board


Some vendors won't render the outside negative space of the circuitboard
correctly in their uploader tool, but it is still fine.

Provide these files to the fabricator:
- [corne-eclipse-mx-dual.zip](/fabrication/!for-fabricator-production/pcb/corne-eclipse-mx-dual.zip)

### Plates

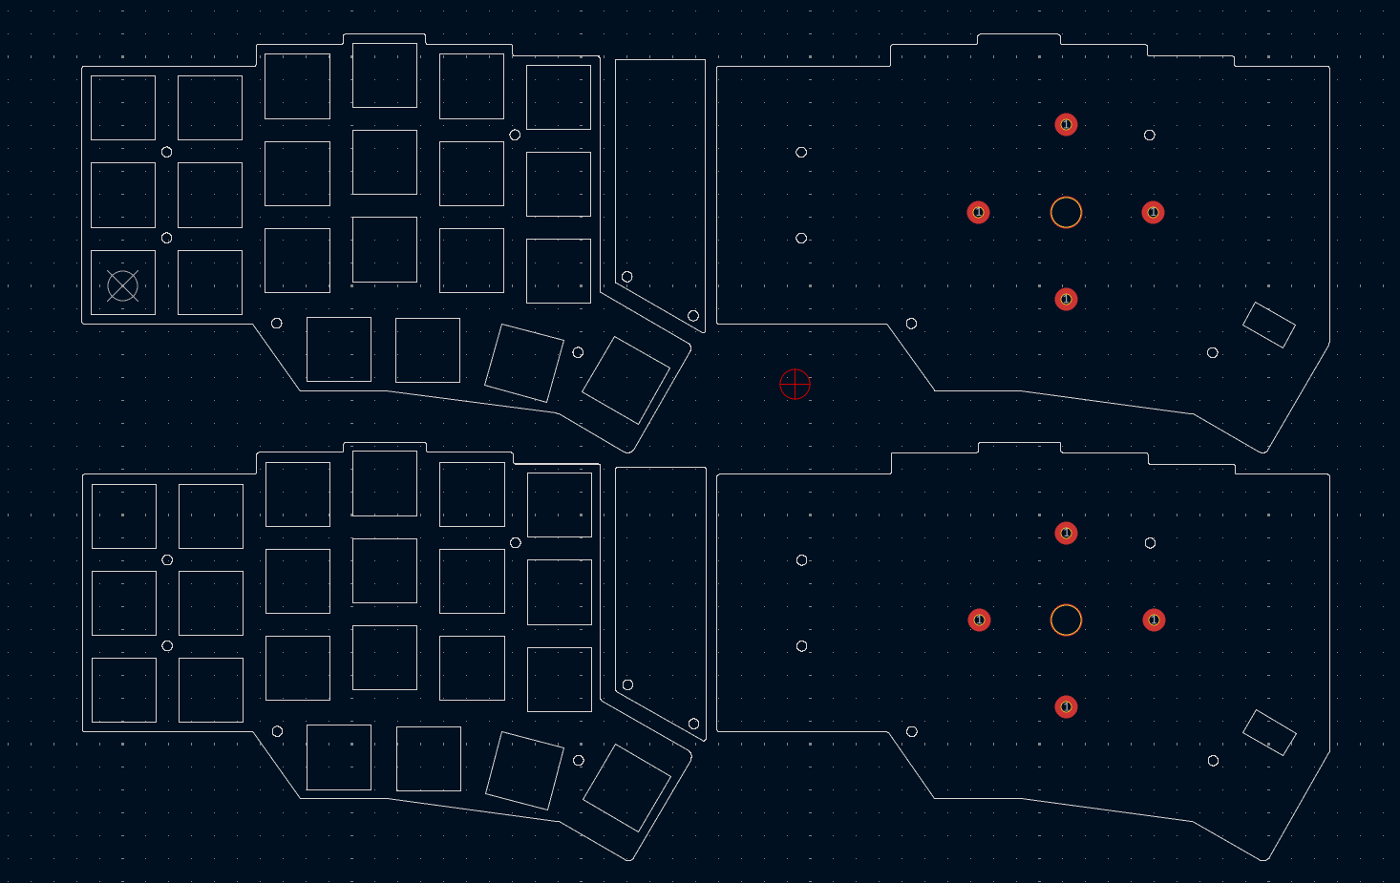
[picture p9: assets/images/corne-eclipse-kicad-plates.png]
Plates


This will need to be cut the same way that circuitboards are. There may be an
extra charge for adding break-away points to the plate print.

Provide these files to the fabricator:
- [corne-eclipse-plates-mx-or-chocv2-1.5mm.zip](/fabrication/!for-fabricator-production/pcb/corne-eclipse-plates-mx-or-chocv2-1.5mm.zip)

### Shield Case

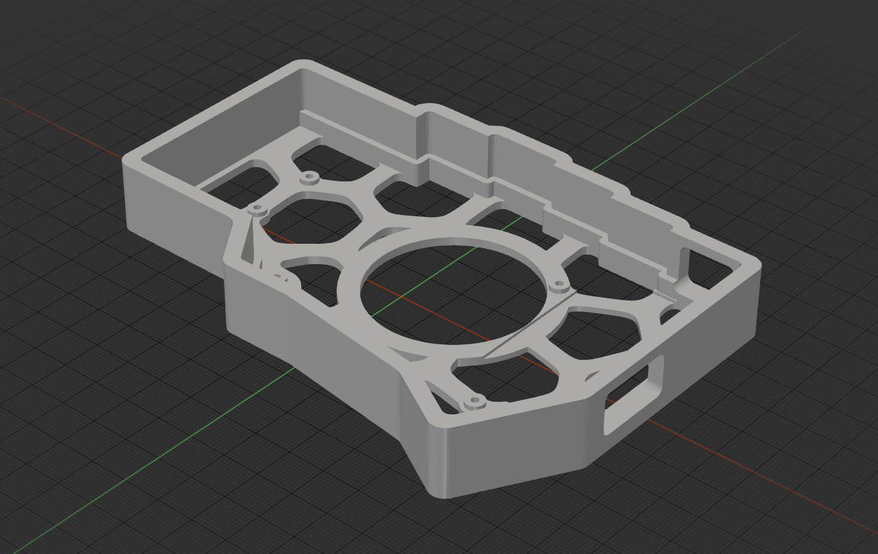
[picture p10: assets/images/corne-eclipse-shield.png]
Shield


Provide these files to the fabricator:
- [corne-eclipse-case-mx-left.stl](/fabrication/!for-fabricator-production/3dprint/cases-standard/corne-eclipse-case-mx-left.stl)
- [corne-eclipse-case-mx-right.stl](/fabrication/!for-fabricator-production/3dprint/cases-standard/corne-eclipse-case-mx-right.stl)

*Note: Some fabricators have gotten pretty good at printing this out in metal.*

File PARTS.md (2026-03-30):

[README](README.md) | [Keymap](KEYMAP.md) | Parts | [Fabrication](FABRICATION.md) | [Building](BUILDING.md) | [Tricks](TRICKS.md)

# Parts

## Electronics

| Required | Quantity | Part | Notes |
|---|---|---|---|
| ✅ | 2 | [nice!nano v2 Microcontroller](https://nicekeyboards.com/nice-nano/) | Bluetooth-enabled. Solder at 270-300C to avoid damaging the nRF52840 chip. |
| ✅ | 2 | [JST Connector (S2B-PH-SM4-TB)](https://www.digikey.com/en/products/detail/jst-sales-america-inc/S2B-PH-SM4-TB/926655) | For battery connection with line passthrough. |
| ✅ | 2 | [SPDT Right-Angle Slide Switch](https://www.digikey.com/en/products/detail/eao/09-10290-01/8733108) | Power switch. |
| ✅ | 2 | [750mAh Battery (403450)](https://www.amazon.com/Liter-energybattery-Battery-Rechargeable-Connector/dp/B09FSY7N9G) | 3.7V LiPo, 4 x 34 x 50mm. JST PH 2.0 terminated. Important: The hot (red) line of the battery should go on the right side when looking down at either corne pcb from above. |
| ✅ | 100+ | [SMD Diodes](https://boardsource.xyz/products/diode-smd) | 1N4148W or equivalent. |
| ✅ | 42+ | [MX Hotswap Sockets](https://cannonkeys.com/products/kailh-mx-hotswap-sockets) | For plugging your switches into. |
| ✅ | 2 | [Mill Max Low Profile Sockets & Pins](https://splitkb.com/products/mill-max-low-profile-sockets?variant=31945995845709) | For socketing the nice!nano. Make sure you get the Mil Max pins with it! |
| ✅ | 2 | [Reset Switches](https://splitkb.com/products/reset-buttons) | Tactile SMD reset switches. |
| ❌ | 1-2 | [nice!view Display](https://nicekeyboards.com/nice-view/) | The left is the most important, as it shows active bluetooth state and profile. Be sure to get pins/sockets that accomodate your socketing height of the nice!nano. |
| ❌ | 1-2 | [Alps EC11 Rotary Encoder](https://www.mouser.com/ProductDetail/Alps-Alpine/EC11N1524402?qs=W%2FMpXkg%252BdQ5mmk2EdvtXAA%3D%3D) | Alps Alpine EC11N1524402 or EC11 compatible encoder. |

## Switches & Keycaps

| Required | Quantity | Part | Notes |
|---|---|---|---|
| ✅ | 42+ | MX Switches | MX-compatible switch set. |
| ✅ | 42+ | MX Keycaps | MX-compatible keycap set. |
| ❌ | 1-2 | [Encoder Rotary Knobs](https://www.gloriousgaming.com/products/gmmk-pro-keyboard-rotary-knob) | Any EC11-compatible knobs if you installed an encoder. |

## Plates & Case

| Required | Quantity | Part | Notes |
|---|---|---|---|
| ❌ | 2 | [OLED Cover Kit](https://keebd.com/en-us/products/corne-acrylic-oled-cover-kit) | Protective acrylic covers. If you find these without the standoffs and screws, you'll need to get those yourself. |
| ❌ | 2 | [SplitKB Tenting Pucks](https://splitkb.com/products/tenting-puck?_pos=1&_sid=b9942abea&_ss=r) | Mounted to the PCB via 4 included screws. May have options that include the Manfrotto MP3-BK. |
| ❌ | 2 | [Small Desk Tripod](https://www.manfrotto.com/global-en/pocket-support-large-black-mp3-bk/) | Manfrotto MP3-BK Pocket Tripod or similar. Only if you didn't get it bundled above. |

## Hardware

I haven't yet verified the exact screws, so this list may not be exact. YMMV.

| Required | Quantity | Part | Notes |
|---|---|---|---|
| ✅ | 10 | [M2x8mm Countersunk Screws](https://www.aliexpress.us/item/2251832781782755.html) | Standoff bottom case screws. |
| ✅ | 36 | [M2x5mm Button Head Screws](https://www.aliexpress.us/item/2251832780910689.html) | Standoff top plate screws. |
| ✅ | 10 | [M2x8mm Female-Female Standoffs](https://www.aliexpress.us/item/2255801085594177.html) |  |

## Fabricated Parts

You will also need the following parts from the [Fabrication](FABRICATION.md) page:
- 1x Circuit board set (left and right)
- 1x Plate set (left and right)
- 1x Left Shield Case
- 1x Right Shield Case

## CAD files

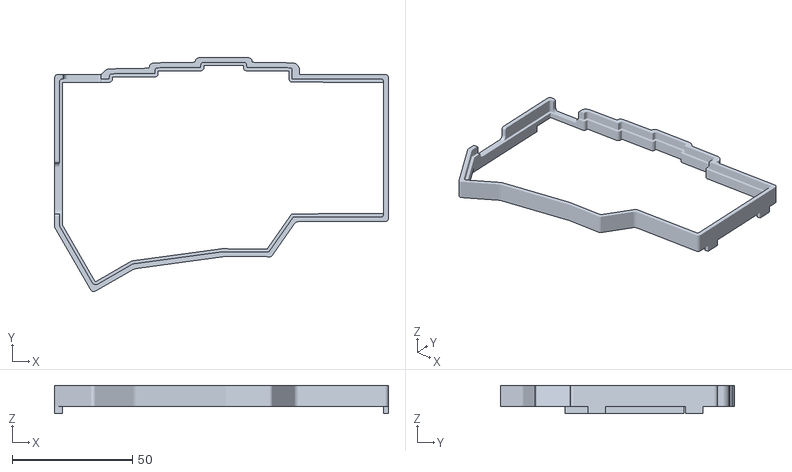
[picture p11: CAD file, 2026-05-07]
fabrication/!for-fabricator-production/3dprint/cases-rgb/corne-eclipse-acrylic-lp-open-right.stl
138.9 x 97.3 x 11.8

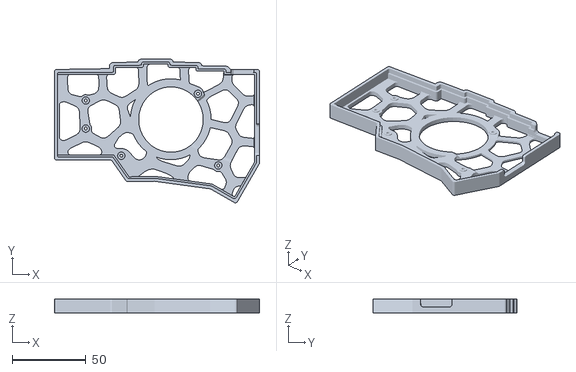
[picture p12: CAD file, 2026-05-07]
fabrication/!for-fabricator-production/3dprint/cases-standard/corne-eclipse-case-lp-left.stl
138.8 x 97.3 x 9.75

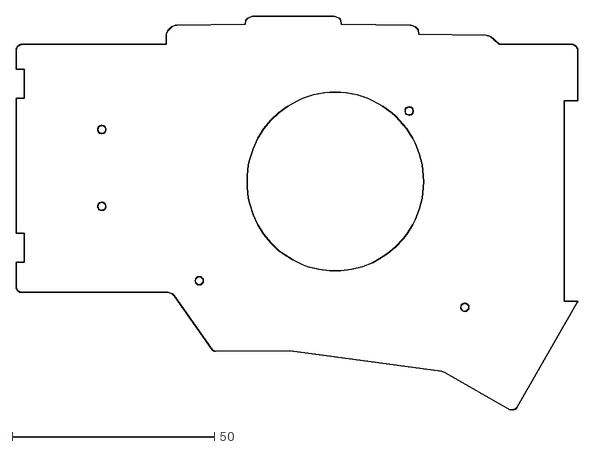
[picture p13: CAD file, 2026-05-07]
fabrication/!for-fabricator-production/cutout/corne-eclipse-shell-acrylic-base/corne-eclipse-shell-acrylic-base.dxf
138.8 x 97.3

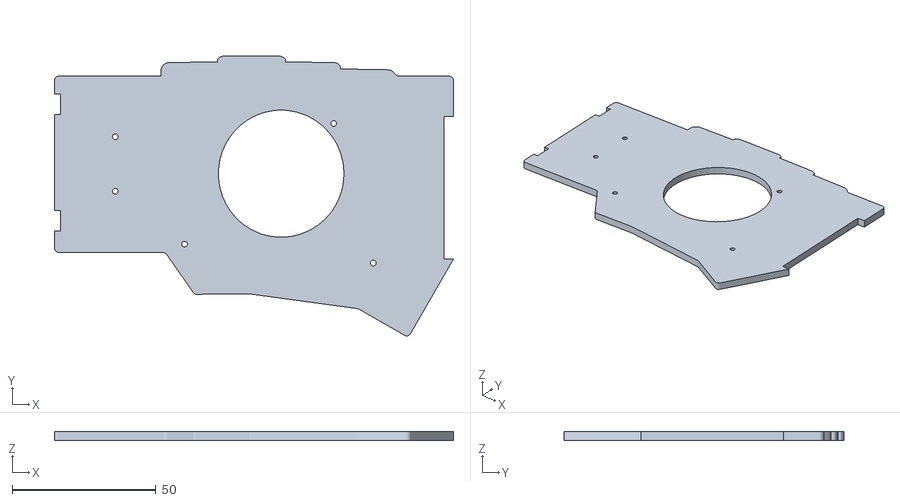
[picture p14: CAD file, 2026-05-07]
fabrication/!for-fabricator-production/cutout/sources/corne-eclipse-acrylic-lp-acrylic-only.stl
138.8 x 97.3 x 3.00

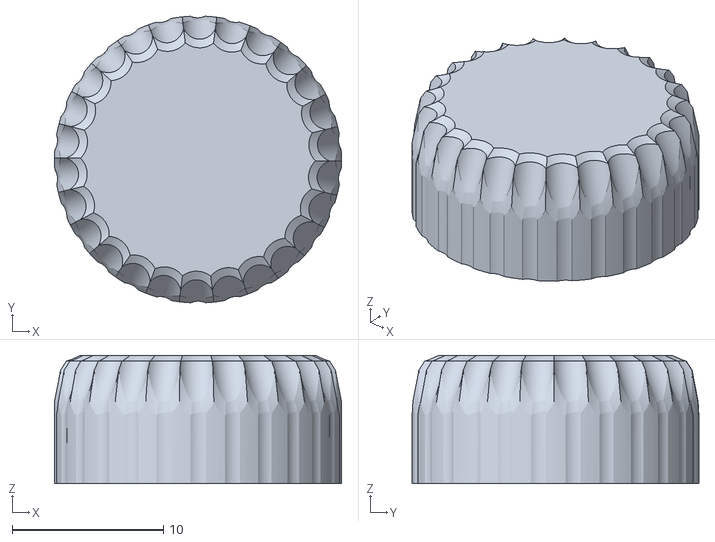
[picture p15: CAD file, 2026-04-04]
fabrication/encoder knob/ec12_with_skirt.stl
19.0 x 19.0 x 8.50

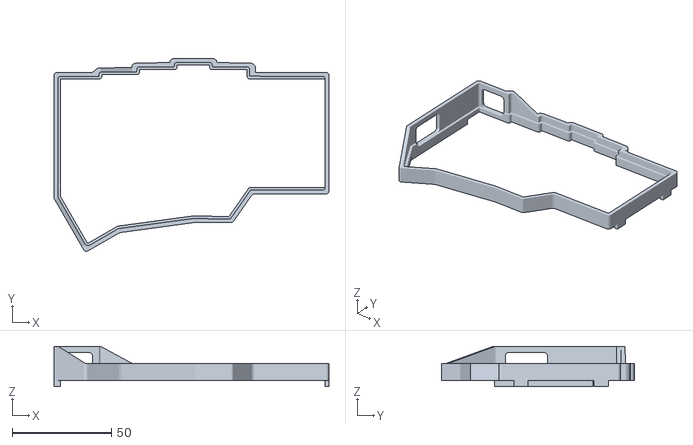
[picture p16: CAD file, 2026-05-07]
fabrication/!for-fabricator-production/3dprint/cases-rgb/corne-eclipse-acrylic-lp-closed-right.stl
138.9 x 97.3 x 20.3

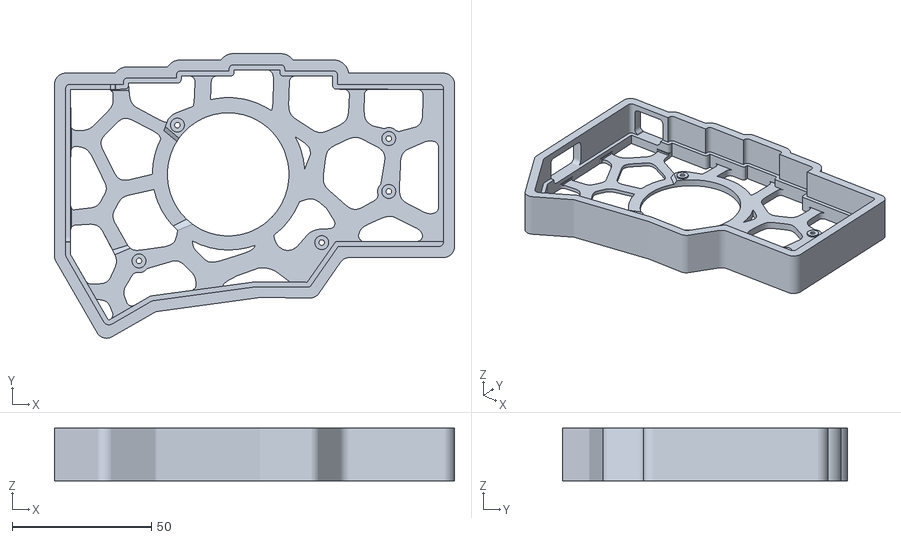
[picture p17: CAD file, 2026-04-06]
fabrication/!for-fabricator-production/3dprint/cases-standard/corne-eclipse-case-mx-right.stl
143.7 x 102.2 x 18.9

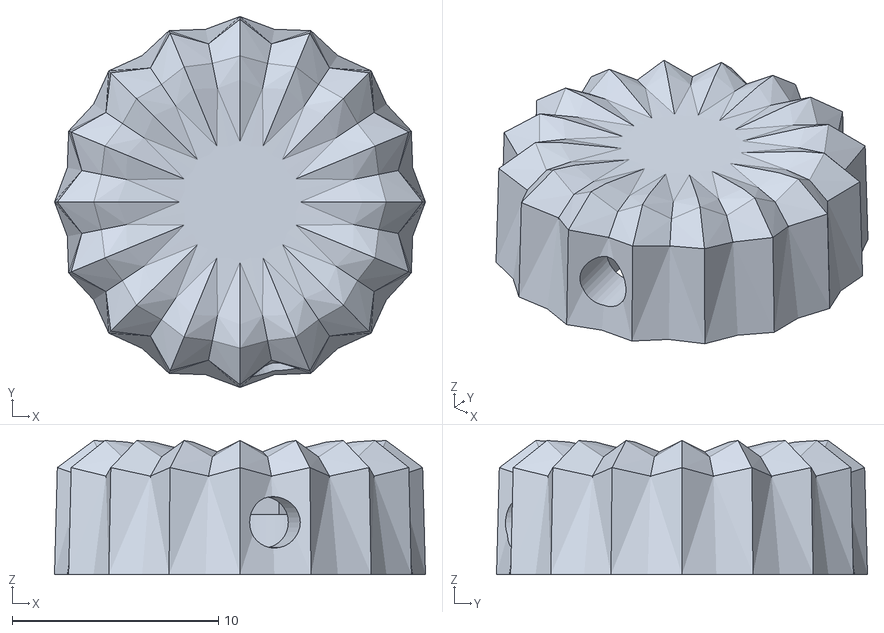
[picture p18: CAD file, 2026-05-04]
fabrication/!for-fabricator-production/3dprint/encoders/corne-eclipse-enc-lotus-lp-setscrew.stl
18.0 x 18.0 x 6.50

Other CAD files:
fabrication/!for-fabricator-production/3dprint/cases-rgb/corne-eclipse-acrylic-lp-open-left.stl
fabrication/!for-fabricator-production/3dprint/cases-standard/corne-eclipse-case-lp-right.stl
fabrication/!for-fabricator-production/3dprint/cases-rgb/corne-eclipse-acrylic-lp-closed-left.stl
fabrication/!for-fabricator-production/3dprint/cases-standard/corne-eclipse-case-mx-left.stl
assets/projects/corne-eclipse-case-lp-left.blend
assets/projects/corne-eclipse-case-mx-left.blend
assets/projects/corne-eclipse-enc-lotus.blend
assets/projects/wip/corne-eclipse-acrylic-lp-left.blend

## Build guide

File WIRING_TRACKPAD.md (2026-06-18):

[README](README.md) | [Keymap](KEYMAP.md) | [MX Parts](PARTS_MX.md) | [Building](BUILDING.md) | [Tricks](TRICKS.md)

# Wiring a Trackpad

The Corne Eclipse can host a trackpad on either half (the PCB is reversible). The same wiring approach applies to either side; just hand-wire to the pads on the half where the trackpad is installed.

Two trackpad modules are supported:

- **Azoteq TPS43** (rectangular, 43x40 mm). EOL as of April 2024; aftermarket stock only.
- **Cirque Pinnacle** (GlidePoint Circle TM040040 40 mm round / TM035035 35 mm round). Actively produced, recommended for new builds.

Both modules use the same I2C interface and the same interrupt pin. A single trackpad firmware variant per half (`left_trackpad_corne_eclipse_<layout>.zmk.uf2` or `right_trackpad_corne_eclipse_<layout>.zmk.uf2`) bundles both drivers and auto-detects whichever module is wired up.

## What gets disabled

The trackpad communicates over I2C using pins P0.17 (SDA) and P0.20 (SCL). The nice!view display on that half uses these same physical pins for SPI. The nRF52840 cannot run both I2C and SPI on the same pins simultaneously, so **the half with the trackpad cannot use a nice!view display**. The OLED display is also disabled in the trackpad firmware to avoid conflicts.

The other half's display is unaffected.

The encoder is **not** affected: the trackpad RDY/DR signal lives on a different pad (the SPI_SCK net = pad 14 = pro_micro D16 / P0.10) than the encoder pins, so the rotary encoder still works alongside a trackpad. A key switch in the encoder position also still works.

---

## Wiring

### Prerequisites

- A trackpad module of your choice:
  - Azoteq TPS43-201A-B (limited aftermarket availability, e.g. [HolyKeebs](https://holykeebs.com/products/touchpad-module))
  - Cirque GlidePoint Circle **TM040040** (40 mm) or **TM035035** (35 mm), available from [keycapsss](https://keycapsss.com/keyboard-parts/parts/211/glidepoint-cirque-trackpad-tm040040-tm035035), DigiKey, Mouser, or Cirque directly
- 5 thin wires (28-30 AWG recommended)
- Soldering iron and solder
- The nice!view display on that half must be removed (the trackpad reuses its I2C pins)

Cirque modules ship in a few form factors, most commonly a flat self-adhesive flex or an FFC ribbon. The electrical connections are the same across them; only the physical pad layout or connector differs. Match each wire below by its signal name on your specific module.

### Wiring Diagram

| Trackpad Signal | PCB Pad / Net | nice!nano Pin | Notes |
|---|---|---|---|
| SDA | I2C data | P0.17 (pro_micro SDA / pad 2) | Reuses the display's SDA pad |
| SCL | I2C clock | P0.20 (pro_micro SCL / pad 3) | Reuses the display's SCL pad |
| RDY (Azoteq) / DR (Cirque) | **SPI_SCK net (pad 14)** | P0.10 (pro_micro D16) | Active high. Hand-wire to the pad labeled **SPI_SCK** on the PCB (silkscreen pad 14). |
| VCC / VDD / 3V3 | 3.3 V | 3.3 V rail | From the nice!nano 3.3 V rail. Labeled `3V3` on Azoteq, `VDD` on Cirque. Cirque ASIC is 3.3 V only; do not wire to 5 V. |
| GND | Ground | GND | Any ground pad |

The signal names differ slightly between modules (RDY on Azoteq, DR on Cirque) but go to the same nice!nano pin and serve the same purpose: a data-ready interrupt from the trackpad.

### Connection points on the PCB

**SDA and SCL:** Solder to the nice!nano's pro_micro SDA and SCL pads. The pads where the nice!view display connected on that half are a convenient solder point.

**RDY / DR:** Solder to the PCB pad labeled **SPI_SCK** (silkscreen pad 14). This pad normally carries the nice!view display's SPI clock signal. With the display removed and the trackpad firmware loaded, the SPI peripheral no longer uses this pad and it becomes the I2C interrupt input. The encoder pins are untouched.

**Power:** Use the nice!nano's 3.3 V and GND pads on that half.

### Notes

- Azoteq TPS43 I2C address is **0x74**; Cirque Pinnacle is **0x2A** by default. If your Cirque module has the R1 solder jumper bridged the address becomes **0x2C**, in which case you need to edit `reg = <0x2a>` to `<0x2c>` in the overlay before building from source.
- RDY / DR is **active high**; no pull-up resistor is needed.
- The TPS43 requires a **1 mm dielectric overlay** (glass or acrylic) for proper capacitive sensing. The HolyKeebs kit includes a matte grey glass overlay.
- Keep wires as short as practical to reduce I2C noise.
- Cursor direction (X/Y polarity) depends on how you mount the module relative to the keyboard. If movement feels inverted after flashing, adjust the `input-processors` line for the relevant trackpad in `config/boards/shields/corne_eclipse/corne_eclipse_<half>.overlay` and rebuild from source.

## Firmware

**A trackpad is flashed as a coordinated pair, not one half at a time.** The left half is the split central (the half that talks to your computer); the right half is the peripheral. A trackpad on the peripheral can't reach the computer on its own - it forwards its input to the central over the split link - so the central's firmware has to be built to receive it. Flashing only the trackpad half will result in no cursor movement.

Each release zip is organized into scenario folders. Pick the one that matches where your trackpad is, and flash **both** `.uf2` files in that folder (left to the left half, right to the right half):

| Your build | Folder | Flash to left | Flash to right |
|---|---|---|---|
| No trackpad | `no trackpads/` | `standard_left_…` | `standard_right_…` |
| Trackpad on the **right** (peripheral) | `trackpad on peripheral side/` | `trackpad_peripheral_left_…` | `trackpad_peripheral_right_…` |
| Trackpad on the **left** (central) | `trackpad on central side/` | `trackpad_central_left_…` | `trackpad_central_right_…` |

The half that physically has the trackpad can't drive a nice!view display (the trackpad reuses the display's I2C pins). If the other half has a display fitted, the status widgets render there. Each trackpad firmware bundles both the Azoteq IQS5xx and Cirque Pinnacle drivers, so one build works for either module. See [FLASHING.md](FLASHING.md) for flashing instructions.

> If you flash mismatched halves (e.g. a `trackpad_peripheral_right` with a `standard_left`), the trackpad will not work - the central won't be listening for the forwarded input. Always flash both halves from the same folder.

## Trackpad Features

Both trackpads support:

- Single-finger cursor movement
- Single-finger tap for left click
- Two-finger vertical and horizontal scroll

The **Azoteq TPS43** has a multi-touch gesture engine and additionally supports:

- Two-finger tap for right click
- Three-finger tap for middle click
- **Tap-then-hold drag-lock** (tap, then touch again within 250 ms to grab,
  then drag; the lock holds across finger lifts and is released by a tap, or
  by a multi-finger tap as a guaranteed escape). The drag tracks the very
  first move of the second touch — no hold-time wait. Note that the initial
  tap fires a left click, so use Ctrl/Cmd-click for multi-select first if
  you intend to drag a group selection.

> **Pinch / expand zoom is not enabled.** It is implemented (the chip's zoom
> gesture, mapped to Ctrl+scroll on the host), but the 43 mm pad is too small for
> the chip to detect a pinch reliably — the two contacts barely change
> separation, so zoom rarely triggers, and at sensitive thresholds it steals
> two-finger scroll. So it's left disabled (no other firmware — QMK, the rwalkr
> Rust crate, the Linux driver — ships it either). Use Ctrl + scroll for zoom.

The **Cirque Pinnacle** (GlidePoint Circle) is **single-touch hardware** — it can only track one finger at a time. It therefore cannot do any two-finger or three-finger gesture, and double-tap-drag is not implemented for it; it provides cursor movement, tap-to-click, and scroll. This is a hardware limitation of the Pinnacle, not a firmware choice.

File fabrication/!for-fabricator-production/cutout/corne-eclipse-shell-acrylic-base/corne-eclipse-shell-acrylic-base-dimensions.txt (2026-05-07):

File: corne-eclipse-shell-acrylic-base
Width:  138.83 mm (5.47 in)
Height: 97.34 mm (3.83 in)

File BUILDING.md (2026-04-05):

[README](README.md) | [Keymap](KEYMAP.md) | [MX Parts](PARTS_MX.md) | Building | [Tricks](TRICKS.md)

# Building

Coming Soon

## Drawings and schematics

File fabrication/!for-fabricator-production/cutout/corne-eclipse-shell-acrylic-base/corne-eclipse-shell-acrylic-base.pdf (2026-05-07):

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

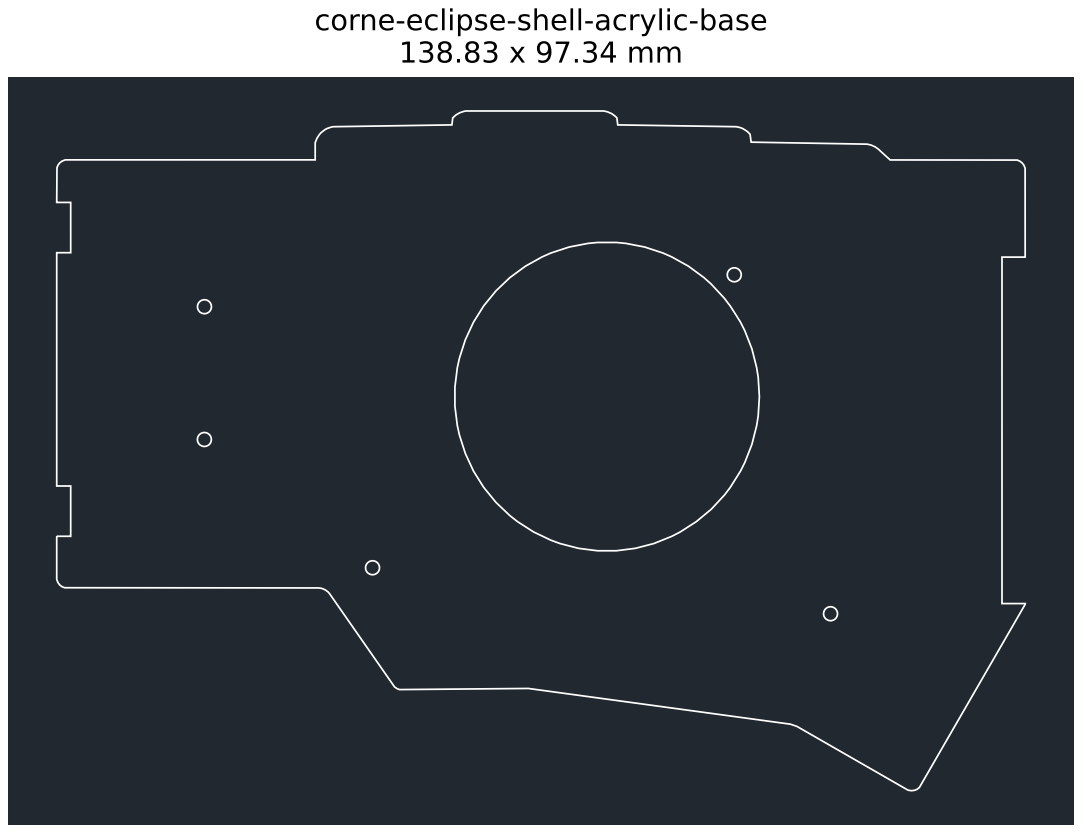
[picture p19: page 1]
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

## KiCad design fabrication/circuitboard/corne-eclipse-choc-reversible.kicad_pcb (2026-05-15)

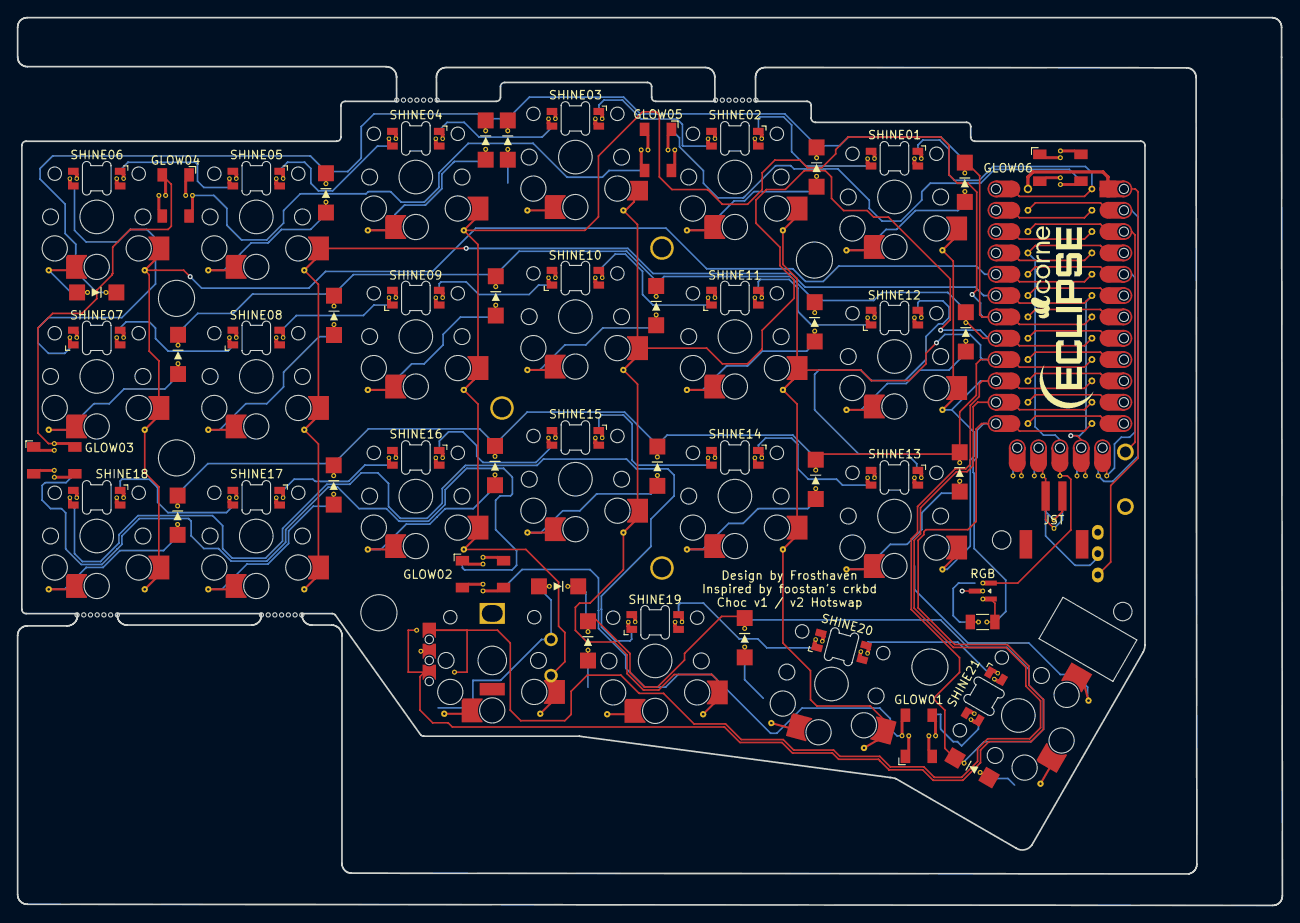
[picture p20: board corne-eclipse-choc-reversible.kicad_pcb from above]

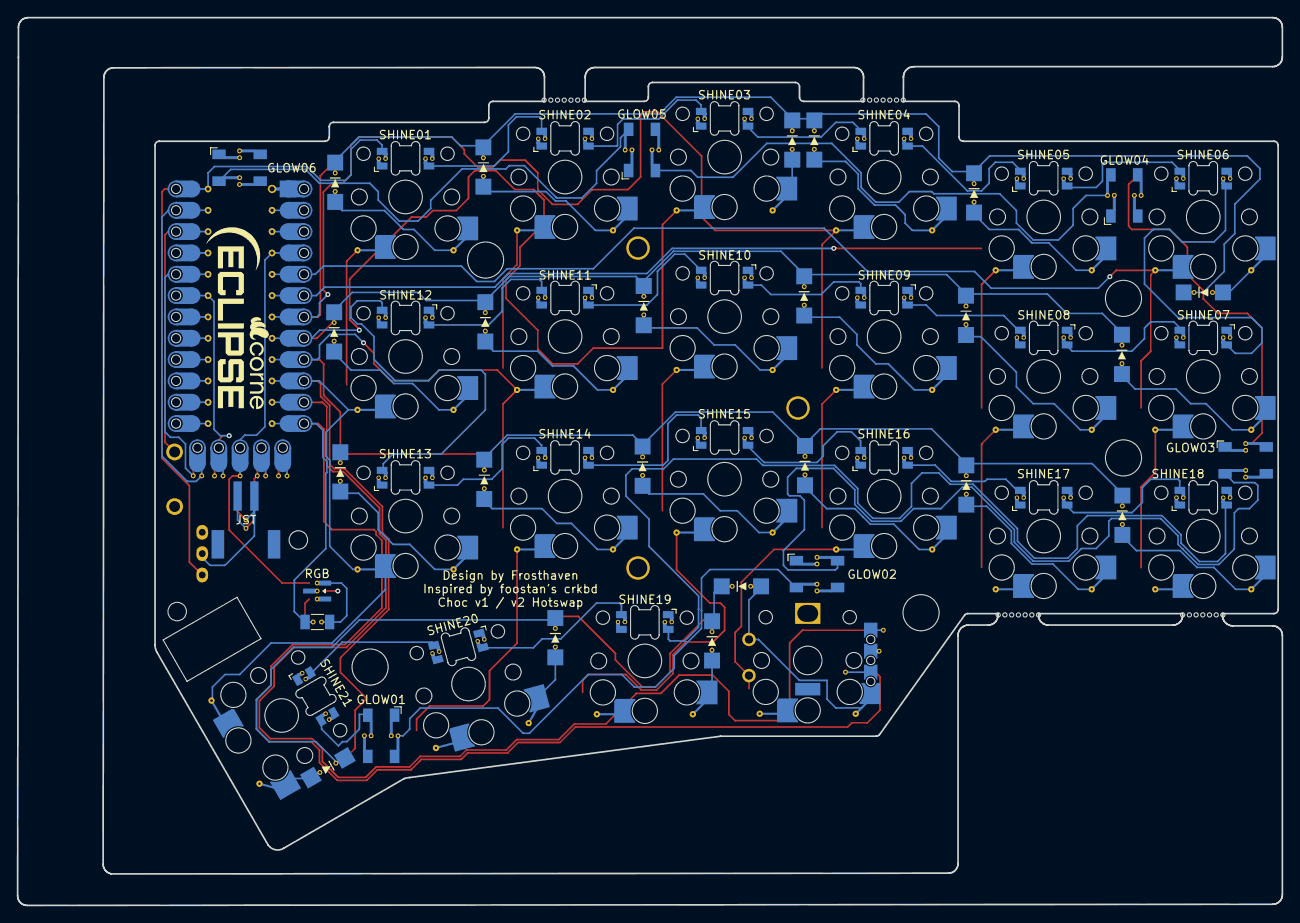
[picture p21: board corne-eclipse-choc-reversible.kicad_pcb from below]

Board: 4 copper layers, 150.6 x 105.7 mm, 91 parts (51 on the bottom side), 71 nets.

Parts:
BT1, BT2, BT3, BT4: Breakaway_Tabs
D1, D2, D3, D4, D5, D6, D7, D8, D9, D10, D11, D12, D13, D14, D15, D16, D17, D18, D19, D19B, D20, D21: D; ComboDiode-reversible
ENC1: ENC_SW_EC12_Choc; ENC_SW_EC12_Choc-reversible
GLOW01, GLOW02, GLOW03, GLOW04, GLOW05, GLOW06: WS2812B; SK6812_5050-reversible
J2: OLED; niceview-reversible
JPT1: JST Passthrough
JST: JST_PH-reversible
MH1, MH2, MH3, MH4, MH5, MH10, MH11: Val**; M2_HOLE_v2
PWR1: PowerSW-reversible
R1: 10k; R_1206-reversible
RGBMOS: AO3401A; SOT-23-reversible
RSW1: SW_PUSH; ResetSW-reversible
SHINE01, SHINE02, SHINE03, SHINE04, SHINE05, SHINE06, SHINE07, SHINE08, SHINE09, SHINE10, SHINE11, SHINE12, SHINE13, SHINE14, SHINE15, SHINE16, SHINE17, SHINE18, SHINE19, SHINE20, SHINE21: LED_6028R; SK6812_mini_e-reversible
SW1, SW2, SW3, SW4, SW5, SW6, SW7, SW8, SW9, SW10, SW11, SW12, SW13, SW14, SW15, SW16, SW17, SW18, SW20, SW21, SW22: SW_Choc_v1v2_HS; Choc_Hotswap-reversible
TP2: Tenting Puck; Tenting_Puck-reversible
U1: nice!nano; ProMicro-reversible

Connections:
BAT+: JST.2, PWR1.2
COL0: SW1.1, SW7.1, SW13.1, U1.20
COL1: SW2.1, SW8.1, SW14.1, U1.19
COL2: ENC1.1, ENC1.S2, SW3.1, SW9.1, SW15.1, U1.18
COL3: SW4.1, SW10.1, SW16.1, SW20.1, U1.17
COL4: SW5.1, SW11.1, SW17.1, SW21.1, U1.16
COL5: SW6.1, SW12.1, SW18.1, SW22.1, U1.15
ENC_A: ENC1.B, U1.11
ENC_B: ENC1.A, U1.12
EXT_PWR: R1.1, RGBMOS.2, U1.13
GND: ENC1.C, GLOW01.3, GLOW02.3, GLOW03.3, GLOW04.3, GLOW05.3, GLOW06.3, J2.4, JST.1, RSW1.2, SHINE01.3, SHINE02.3, SHINE03.3, SHINE04.3, SHINE05.3, SHINE06.3, SHINE07.3, SHINE08.3, SHINE09.3, SHINE10.3, SHINE11.3, SHINE12.3, SHINE13.3, SHINE14.3, SHINE15.3, SHINE16.3, SHINE17.3, SHINE18.3, SHINE19.3, SHINE20.3, SHINE21.3, TP2.1, U1.3, U1.4, U1.23
LED_CHAIN: SHINE01.4, U1.1
LED_PWR: GLOW01.1, GLOW02.1, GLOW03.1, GLOW04.1, GLOW05.1, GLOW06.1, RGBMOS.3, SHINE01.1, SHINE02.1, SHINE03.1, SHINE04.1, SHINE05.1, SHINE06.1, SHINE07.1, SHINE08.1, SHINE09.1, SHINE10.1, SHINE11.1, SHINE12.1, SHINE13.1, SHINE14.1, SHINE15.1, SHINE16.1, SHINE17.1, SHINE18.1, SHINE19.1, SHINE20.1, SHINE21.1
unnamed: D1.2, SW1.2
unnamed: D2.2, SW2.2
unnamed: D3.2, SW3.2
unnamed: D4.2, SW4.2
unnamed: D5.2, SW5.2
unnamed: D6.2, SW6.2
unnamed: D7.2, SW7.2
unnamed: D8.2, SW8.2
unnamed: D9.2, SW9.2
unnamed: D10.2, SW10.2
unnamed: D11.2, SW11.2
unnamed: D12.2, SW12.2
unnamed: D13.2, SW13.2
unnamed: D14.2, SW14.2
unnamed: D15.2, SW15.2
unnamed: D16.2, SW16.2
unnamed: D17.2, SW17.2
unnamed: D18.2, SW18.2
unnamed: D19B.2, ENC1.2, ENC1.S1
unnamed: D19.2, SW20.2
unnamed: D20.2, SW21.2
unnamed: D21.2, SW22.2
RAW: PWR1.1, U1.24
RESET: RSW1.1, U1.22
ROW1: D1.1, D2.1, D3.1, D4.1, D5.1, D6.1, U1.7
ROW2: D7.1, D8.1, D9.1, D10.1, D11.1, D12.1, U1.8
ROW3: D13.1, D14.1, D15.1, D16.1, D17.1, D18.1, U1.9
ROW4: D19.1, D19B.1, D20.1, D21.1, U1.10
VCC: J2.3, R1.2, RGBMOS.1, U1.21
VIEW_CS: J2.5, U1.2
VIEW_MOSI: J2.1, U1.5
VIEW_SCK: J2.2, U1.6
led1-led2: SHINE01.2, SHINE02.4
led2-led3: SHINE02.2, SHINE03.4
led3-led4: SHINE03.2, SHINE04.4
led4-led5: SHINE04.2, SHINE05.4
led5-led6: SHINE05.2, SHINE06.4
led6-led7: SHINE06.2, SHINE07.4
led7-led8: SHINE07.2, SHINE08.4
led8-led9: SHINE08.2, SHINE09.4
led9-led10: SHINE09.2, SHINE10.4
led10-led11: SHINE10.2, SHINE11.4
led11-led12: SHINE11.2, SHINE12.4
led12-led13: SHINE12.2, SHINE13.4
led13-led14: SHINE13.2, SHINE14.4
led14-led15: SHINE14.2, SHINE15.4
led15-led16: SHINE15.2, SHINE16.4
led16-led17: SHINE16.2, SHINE17.4
led17-led18: SHINE17.2, SHINE18.4
led18-led19: SHINE18.2, SHINE19.4
led19-led20: SHINE19.2, SHINE20.4
led20-led21: SHINE20.2, SHINE21.4
led21-led23: GLOW01.4, SHINE21.2
led23-led24: GLOW01.2, GLOW02.4
led24-led25: GLOW02.2, GLOW03.4
led25-led26: GLOW03.2, GLOW04.4
led26-led27: GLOW04.2, GLOW05.4
led27-led28: GLOW05.2, GLOW06.4

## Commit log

2026-03-30 Import Project
    [corne-eclipse-B_Cu.gbl, corne-eclipse-B_Mask.gbs, corne-eclipse-B_Silkscreen.gbo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]
2026-04-03 fix(encoder): swap horizontal left/right scroll
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2026-04-04 feat(fabrication): add universal, choc v1/v2, and mx board variants
    - Custom universal switch footprint (MX + Choc v1/v2 hotswap, south-facing)
    - Separate Choc v1/v2 footprint (compact pads, no MX overlap)
    - Separate MX-only footprint
    - Three PCB variants: universal, choc, mx
    - Choc and MX plate variants with mouse bite bridges
    - Custom tenting puck (no center hole, smaller annular rings)
    - EC11 encoder swapped to EC12E
    - LED pad remapping for marbastlib Choc LED footprint
    - Silkscreen cleanup on MCU, encoders, reset, JST, nice!view
    - All net assignments verified against original
    [corne-eclipse-choc.kicad_pcb, corne-eclipse-mx.kicad_pcb, corne-eclipse-universal-plates-chocv1-1.2mm.kicad_pcb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]
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2026-04-05 wip: v3 mx+choc variants
    [corne-eclipse-choc.kicad_pcb, corne-eclipse-mx.kicad_pcb]
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2026-04-05 fix: DEVSYM encoder should use vertical scroll
2026-04-05 wip: silkscreen, QR codes, plate renames, LED34 cleanup
    [corne-eclipse-choc.kicad_pcb, corne-eclipse-mx.kicad_pcb, corne-eclipse-plates-chocv1-1.2mm.kicad_pcb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]
2026-04-05 wip: logos, silkscreen cleanup, choc shield STLs, diode alignment
    [corne-eclipse-choc.kicad_pcb, corne-eclipse-mx.kicad_pcb, corne-eclipse-plates-chocv1-1.2mm.kicad_pcb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]
2026-04-05 chore: rename choc shield STLs to lp (low-profile)
    [corne-eclipse-shield-lp-left.stl, corne-eclipse-shield-lp-right.stl]
2026-04-07 feat(pcbs): finished MX/Choc1/Choc2 plates; choc boards
    [corne-eclipse-choc.kicad_pcb, corne-eclipse-mx.kicad_pcb]
2026-04-08 feat(case): more rounded edges instead of sharp for lp case
    [corne-eclipse-case-lp-left.stl, corne-eclipse-case-lp-right.stl]
2026-04-08 feat(case): more curved edges on lp case
    [corne-eclipse-case-lp-left.blend]
2026-04-08 wip(pcb): better alignment of components on choc pcb
    [corne-eclipse-choc.kicad_pcb, corne-eclipse-mx.kicad_pcb]
2026-04-08 fix(pcb): screw hole alignment to case adjustments
    [corne-eclipse-choc.kicad_pcb, corne-eclipse-mx.kicad_pcb]
2026-04-08 wip: rgb/choc
    [corne-eclipse-choc.kicad_pcb]
2026-04-08 fix(pcbs): aligned screw holes on lp and mx
    [corne-eclipse-choc.kicad_pcb, corne-eclipse-mx.kicad_pcb, corne-eclipse-plates-chocv1-1.2mm.kicad_pcb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]
2026-04-08 wip(pcbs): choc layout done, mx layout started
    [corne-eclipse-choc.kicad_pcb, corne-eclipse-plates-chocv1-1.2mm.kicad_pcb, corne-eclipse-plates-mx-or-chocv2-1.5mm.kicad_pcb]
2026-04-09 feat(pcb): wiring ready
    [corne-eclipse-choc.kicad_pcb, corne-eclipse-mx.kicad_pcb]
2026-04-09 wip: pcbs
    [corne-eclipse-mx.kicad_pcb]
2026-04-09 feat(pcb): split mx design into north-facing and south-facing
    [corne-eclipse-mx-north.kicad_pcb, corne-eclipse-mx-south.kicad_pcb]
2026-04-10 wip(pcbs): set board thicknesses
    [corne-eclipse-choc.kicad_pcb, corne-eclipse-mx-north.kicad_pcb, corne-eclipse-plates-chocv1-1.2mm.kicad_pcb]
2026-04-10 wip(pcbs): added pour layers for power/ground
    [corne-eclipse-choc.kicad_pcb, corne-eclipse-mx-north.kicad_pcb, corne-eclipse-mx-south.kicad_pcb]
2026-04-10 feat(pcbs): finished ground and led power planes on all 3
    [corne-eclipse-mx-north.kicad_pcb]
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2026-04-14 wip(pcbs): reversible
    [corne-eclipse-choc-reversible.kicad_pcb, corne-eclipse-mx-north-reversible.kicad_pcb, corne-eclipse-mx-south-reversible.kicad_pcb]
2026-04-15 wip(pcbs): reversible footprints and choc progress
    [corne-eclipse-choc-reversible.kicad_pcb]
2026-04-15 wip(pcbs): reversibles
    [corne-eclipse-choc-reversible.kicad_pcb]
2026-04-15 wip(knobs): updating knob wall thickness
    [encoder.blend]
2026-04-16 wip(pcbs): wiring prep
    [corne-eclipse-choc-reversible.kicad_pcb]
2026-04-16 wip(pcbs): fix invalid outline
    [corne-eclipse-choc-reversible.kicad_pcb]
2026-04-16 wip(pcbs): fix niceview padstack as keyhole polygon
    [corne-eclipse-choc-reversible.kicad_pcb]
2026-04-16 wip(pcbs): wiring
    [corne-eclipse-choc-reversible.kicad_pcb]
2026-04-16 wip(pcbs): reversible encoder polarity + fab cleanup
    Encoder footprints now flip A/B labels per side so the body-on-back
    mount (encoder rotated 180°) lands on the correct nets. Niceview safe
    zones, BT mouse-bite repitch, mask-bridge cleanup, and JLCPCB-friendly
    drill/track minimums.
    [corne-eclipse-choc-reversible.kicad_pcb]
2026-04-16 feat(pcb): choc reversible fab-ready
    [corne-eclipse-choc-reversible.kicad_pcb]
2026-04-16 fix(pcb:choc-reversible): last-second nice!view ring fix
    [corne-eclipse-choc-reversible.kicad_pcb]
2026-04-19 wip(choc): open and closed acrylic cases
    [corne-eclipse-acrylic-lp-closed-left.stl, corne-eclipse-acrylic-lp-closed-right.stl, corne-eclipse-acrylic-lp-left.blend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]
2026-04-19 feat(encoder): no-skirt + set screw design (metal)
    [corne-eclipse-encoder-lp-skirtless-setscrew.stl, corne-eclipse-encoder-lp-skirtless.stl, encoder.blend]
2026-04-20 fix(build): route DEFAULT_TYPING_LAYER through DTS preprocessor
    The -DDEFAULT_TYPING_LAYER=N cmake-arg only set a CMake cache variable
    and never reached the devicetree preprocessor, causing all builds to
    fall through to the Colemak-DH default. Wrapping via DTS_EXTRA_CPPFLAGS
    ensures the define is passed to the DTS C preprocessor.
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2026-04-22 docs(parts): correct MX standoffs to 4mm with updated link
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2026-04-22 docs(readme): add ZMK modifications section
    Covers the nice!view display improvements (battery numeric value, dual
    cell tracking, caps indicator) and the RGB battery optimizations landed
    via zmk-ext-power-smart-idle (20% brightness on battery, auto-off, always
    on when plugged, v3 MOSFET LED power-cut).
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2026-04-22 feat(trackpad): add Cirque Pinnacle as an alternative to the TPS43
    TPS43 went EOL in April 2024 (Azoteq notice); Cirque GlidePoint Pinnacle
    is actively produced and is the recommended trackpad for new builds.
    - west.yml: pull in petejohanson/cirque-input-module.
    - right.overlay: split the single USE_TRACKPAD macro into two explicit
    variants (USE_TRACKPAD_TPS43, USE_TRACKPAD_CIRQUE). Legacy plain
    USE_TRACKPAD is aliased to USE_TRACKPAD_TPS43 for backward compat.
    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
2026-04-26 fix(pcb): fab tolerances on choc reversible
    [corne-eclipse-choc-reversible.kicad_pcb]
2026-04-26 chore(pcb): adjusted panel values
    [corne-eclipse-choc-reversible.kicad_pcb]
2026-04-26 fix(pcb): rename nice!view nets to match SPI pinout (SDA→DISP_MOSI, SCL→DISP_SCK, data→DISP_CS)
    [corne-eclipse-choc-reversible.kicad_pcb]
2026-04-26 fix(pcb): rename nets to match canonical nice!nano pinout (LED_CHAIN, VIEW_*, ROW1-4, COL0-5, ENC_A/B, BAT+)
    [corne-eclipse-choc-reversible.kicad_pcb]
2026-04-26 fix(pcb): rename Net-(U1-Pad24) to RAW (post-switch/diode rail to MCU)
    [corne-eclipse-choc-reversible.kicad_pcb]
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2026-04-30 fix(nice!view): center bullseye dot in profile circle outline
    Switch the assigned-profile outline from lv_canvas_draw_arc (which has
    Bresenham asymmetry at even radii, biasing the rendered pixels toward
    top-left of (cx,cy) and making the 3x3 dot appear shifted bottom-right)
    to lv_canvas_draw_rect with LV_RADIUS_CIRCLE. The rect-with-circle-radius
    gives a symmetric 1-pixel outline of diameter 2*r+1 = 13, so the visual
    center sits exactly on (cx,cy) and the bullseye dot is centered.
2026-05-01 feat(encoder knob): convert to M3 set screw hole
    [corne-eclipse-encoder-lp-skirtless.stl, encoder.blend]
2026-05-02 fix(encoder): better manufacturing tolerances
    [corne-eclipse-encoder-lp-skirtless.stl, encoder.blend]
2026-05-02 fix(encoder): more manufacturing tolerances
    [corne-eclipse-encoder-lp-skirtless.stl, encoder.blend]
2026-05-02 fix(encoder): more tolerance work
    [corne-eclipse-encoder-lp-skirtless.stl, encoder.blend]
2026-05-04 wip(encoder): new design wip
    [encoder-new.blend]
2026-05-04 feat(encoder): Lotus design final
    [corne-eclipse-enc-lotus-lp-setscrew.stl, corne-eclipse-enc-lotus.blend, corne-eclipse-encoder-lp-skirtless-setscrew.stl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]
2026-05-04 fix(encoder): object unit scale fix
    [corne-eclipse-enc-lotus-lp-setscrew.stl, corne-eclipse-enc-lotus.blend]
2026-05-07 feat(revision3): cutouts, case update, etc
    [base_plate.dxf, base_plate.kicad_pcb, choc_switchplates.dxf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]
2026-05-07 fix: cutouts
    [base_plate.dxf, base_plate.kicad_pcb, choc_switchplates.dxf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]
2026-05-12 wip: cutout fabrication outputs removed, kicad backups added
    [base_plate.dxf, choc_switchplates.dxf, screen_cover.dxf]
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2026-05-14 fix(overlay): delete nice!nano stock EXT_POWER node to resolve duplicate ext-power-generic instance
    nice!nano's base DTS defines /EXT_POWER (P0.13) as a convenience for
    boards whose MOSFET gate sits on the default pin. Our gate is on P0.10
    via /ext-power, but both nodes had compatible 'zmk,ext-power-generic'
    and their DT symbols collided to the same identifier (DT_N_S_ext_power).
    Zephyr generated two instances pointing at the same symbol, leaving
    instance 0's control-gpios config undefined and the driver unable to
    reliably drive any pin at boot.
    Deleting the stock node leaves a single, well-defined ext-power-generic
    instance on P0.10. ext_power_generic_init() now correctly drives the
    MOSFET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
2026-05-14 fix(overlay): correct ext-power control pin from P0.10 to P0.09
    ProMicro pad 13 (where the MOSFET gate is wired) maps to P0.09 / D10 on
    nice!nano v2, not P0.10. The wrong pin meant the driver was happily
    flipping P0.10 (which is actually SPI_SCK on pad 14) low at boot while
    the real MOSFET gate stayed pulled up to BAT+ via R1 — LEDs were never
    getting power.
    Fixed by changing control-gpios from <&gpio0 10 ...> to <&gpio0 9 ...>.
2026-05-15 fix(overlay): move dummy SCK off encoder B pin (P1.06 → P1.11)
    The SPI peripheral's dummy SCK was on P1.06, which is pro_micro pad 9 =
    ENC_B. The SPI peripheral toggled SCK at ~4 MHz on the same pin the
    encoder shorts to GND, causing ground bounce that coupled into the MOSI
    line and corrupted SK6812 data while turning the encoder. Moving SCK to
    P1.11 (pad 14, actually unconnected) resolves it.
2026-05-15 fix(pcb): correct MOSFET and GLOW03 net assignments
    Two unrelated net-swap bugs in the choc-reversible PCB, both fixed by
    swapping net metadata and re-routing traces:
    1. SOT-23-reversible footprint (RGBMOS) had Pad 1 and Pad 2 net
    assignments inverted vs. the standard AO3401A pinout, so Gate ended
    up on BAT+ and Source on EXT_PWR (P-FET never switched). Swapped
    Pad 1 → BAT+, Pad 2 → EXT_PWR.
    2. GLOW03's data-line nets were swapped on Pad 2 (DOUT) and Pad 4
    (DIN), so the LED received no data and its DOUT shorted to GLOW02's
    DOUT. Swapped to chain in/out correctly.
    [corne-eclipse-choc-reversible.kicad_pcb]
2026-05-15 feat(build): add dev_rgb_test variant with RGB enabled at boot
    Useful during assembly to verify the LED chain works before you have a
    working keymap with RGB_TOG available. QWERTY layout, both halves. Not
    intended for daily use.
2026-05-15 docs(flashing): recommend settings reset between dev_rgb_test and daily firmware
    ZMK persists "RGB on" state to NVS, so without a reset the daily build
    would boot with RGB on too. Document the dev → reset → daily flow.
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2026-05-15 fix(west): pin smart-idle to last known-good commit 6511488
    Cloud builds were pulling smart-idle@main HEAD which includes:
    - 74b251d: DT_NODELABEL -> DT_COMPAT lookup change
    - 1024e0d: ext_power_enable() at boot
    - 6e663b6: active_state_seen boot grace flag
    These together produce wrong RGB color (red instead of hue 220 blue)
    and break on-battery auto-off timeout. Pinning to 6511488 matches the
    working local build, restoring correct behavior. Will revisit smart-idle
    changes upstream more carefully.
2026-05-15 feat(conf): re-add USB-idle 2h timeout on clean smart-idle base
    Updates west.yml to pin smart-idle to b558980, which is the clean
    6511488 base + USB timeout feature (no DT_NODELABEL/DT_COMPAT change,
    no boot-grace flag — the changes that broke things). Re-adds the conf
    line CONFIG_ZMK_EXT_POWER_SMART_IDLE_USB_TIMEOUT_S=7200 to enable the
    2-hour auto-off on USB.
2026-05-15 fix(conf): move corne_eclipse.conf to config root so ZMK auto-loads it
    The shared shield conf was at config/boards/shields/corne_eclipse/
    corne_eclipse.conf — too deeply nested for ZMK's user-config flow to
    auto-load. Cloud builds were silently ignoring all the customization
    (HUE_START, BRT_START, SMART_IDLE settings, etc.) and using Kconfig
    defaults instead.
    Per ZMK docs: shared <shield>.conf is auto-loaded ONLY at
    config/<shield>.conf. Moving it there fixes the cloud build to match
    local behaviour (blue, brightness clamp, on-battery timeout, USB-idle
    2h auto-off).
2026-05-15 fix(conf): remove undefined CONFIG_ZMK_EXT_POWER_START symbol
    This symbol doesn't exist in Kconfig. It was harmlessly ignored when
    corne_eclipse.conf wasn't being loaded (the bug we just fixed), but
    now that the conf is at the right path and gets auto-loaded, the
    undefined-symbol warning is fatal under Zephyr's strict mode.
    The behaviour this was trying to express (ext-power off at boot
    unless user toggles RGB on) is the default ZMK behaviour anyway —
    no replacement needed.
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2026-05-15 fix(conf): fade idle MOSFET cut over 1s instead of 2s
2026-05-15 feat(conf): enable monotonic battery reporting to hide voltage-relaxation jitter
2026-05-15 feat(ashley): invert encoder polarity for reversed a/b wiring
2026-05-25 encoder: reapply fork divergences (inverted polarity/zoom + ashb13 URLs)
2026-05-27 build(west): bump azoteq driver to 35fac92 (scroll no longer right-clicks)
    The IQS5xx driver now treats any moving two-finger touch as a scroll/zoom
    attempt rather than a tap, so a short two-finger scroll can no longer be
    misclassified as a two-finger tap (right click) on lift.
2026-06-15 build(west): bump cirque + azoteq forks for trackpad PM device support
    Pulls cirque-input-module fork at c9d41b4 (petejohanson's
    feat/idle-waker-wake-from-sleep-fixes cherry-picked) and zmk-driver-azoteq-iqs5xx
    gestures branch at 9c6f2be (new iqs5xx_pm_action). Both drivers now handle
    PM_DEVICE_ACTION_RESUME by re-applying chip config and re-arming their
    data-ready GPIO interrupt -- the trackpad recovers cleanly when the SoC wakes
    from CONFIG_ZMK_SLEEP, no more 'dead until power-cycle' after a long idle.
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2026-06-18 feat(trackpad): tap-then-hold drag-lock (replace chip press-and-hold)
    Swap the Azoteq's press-and-hold engagement for tap-then-hold: a
    1-finger tap followed by another single-finger touch-down within
    250ms latches the left button at touch-down -- the drag tracks the
    very first move, no hold-time wait. Multi-finger landings still
    scroll/zoom cleanly; the drag-lock is still released by a tap (or
    a multi-finger tap as a guaranteed escape).
    DT: remove press-and-hold from both overlays, add tap-then-hold.
    west.yml: bump azoteq fork to ddda9f8 (gestures HEAD); includes the
    tap-then-hold engagement plus a fix for the tap-release race where
    the tap's pending 100ms auto-release could fire mid-drag i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
2026-06-18 feat(encoder): right encoder always scrolls (drop trackpad zoom mode)
    The right encoder previously emitted Ctrl+scroll on trackpad builds
    (via the zoom_encoder behavior and zoom_in/zoom_out macros) and
    plain scroll otherwise. With the trackpad's two-finger scroll
    covering the same gesture, the encoder doesn't need to double as a
    zoom wheel -- unify on scroll for all builds.
    Collapse the TRACKPAD_PERIPHERAL/CENTRAL conditional in the keymap;
    remove the now-unused zoom_encoder behavior and the zoom_in /
    zoom_out macros.
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2026-06-18 build(trackpad): disable experimental zoom
    The chip's pinch/expand gesture never triggered reliably on the
    43mm TPS43 (separation barely changes), and at sensitive thresholds
    it stole two-finger scroll. Drop it entirely:
    - west.yml: bump azoteq fork to a5f71c6 (zoom removed from the
    driver and DT binding).
    - left.overlay: remove tp_zoom_in / tp_zoom_out macros and
    tp_zoom_proc processor along with their includes, and drop the
    input-processors = <&tp_zoom_proc>; references from both the
    split listener and the central-local listener.
    - right.overlay: remove the stale /* zoom; -- disabled */ note on
    the azoteq node.
